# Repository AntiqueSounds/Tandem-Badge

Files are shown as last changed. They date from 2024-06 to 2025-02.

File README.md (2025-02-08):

# Tandem-Badge
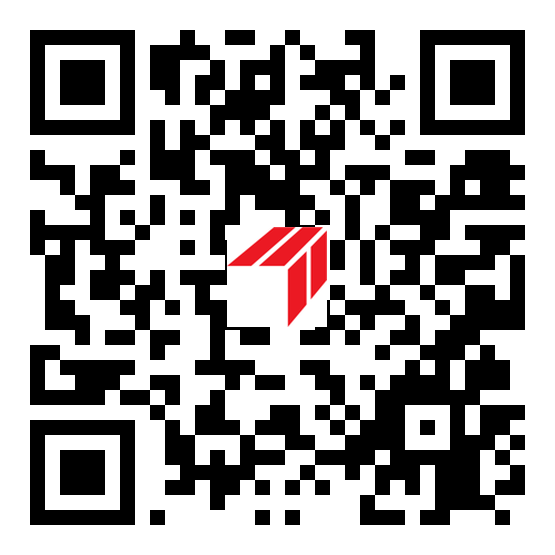
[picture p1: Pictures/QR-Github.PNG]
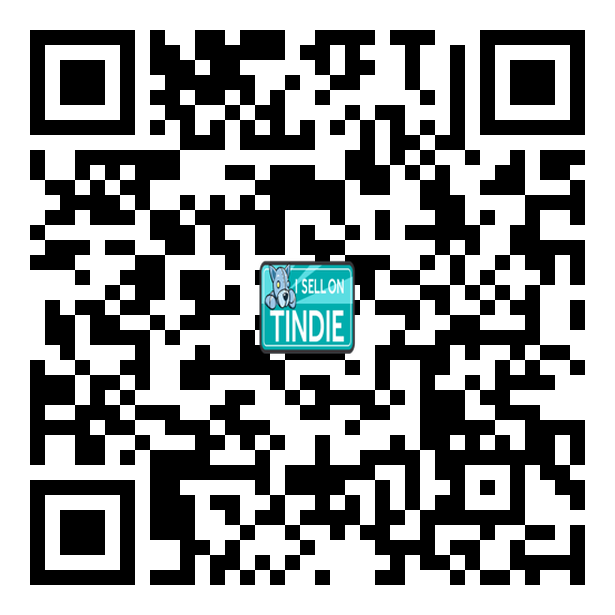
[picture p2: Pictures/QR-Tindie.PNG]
## Tandem 50th Anniversary badge project ✨ &nbsp; &nbsp; &nbsp;    &nbsp; &nbsp; &nbsp; &nbsp;  
This project is a special anniversary badge that can be used for trade shows like the ones used at DefCon.  The standard for SAO badge boards is fully supported in the hardware and software
See:   
[DefCon badges](https://defcon.org/html/links/dc-badge.html)  
[SAO board specs](https://hackaday.io/project/175182-simple-add-ons-sao)

Directions for building the badge and for how to load the software are included here in the top level directory. 

Current software version is V3E (shown on the badge in the lower right corner sideways).   The current badge version is 13 for both top and bottom. The two boards must match versions.  
The SAO boards have separate versioning and do not have to coincide (can be used on any other SAO enabled badge). 

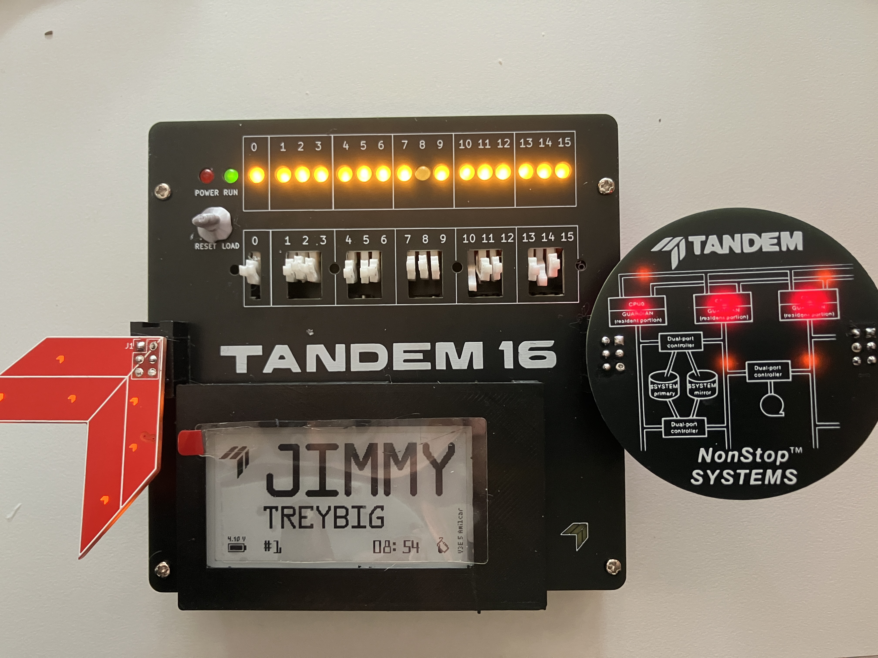
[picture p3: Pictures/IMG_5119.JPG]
Hello my name is


**The switches are FRAGILE, but functional.  Please gently switch them. This was the most difficult part of the whole project. The design and assembly of these switch extensions is still evolving. If a switch extension falls off, it can be "crazy glued" back on.** 

## Functionality
The software has been enhanced to allow serial connection via USB port (115200) to prompt for values to place into persistent memory of the ESP-32. The use of the name loader tool is not unnecessary anymore.

Serial port is set to 115200. The USB is for powerand for serial communication. (Configuration or debugging.) Serial Prompts are for the values shown below in the software persistent memory section. 

Badge software updates can be loaded and upgraded separately from the name load.  There is no need to use the name loader tool. Once set, they persist until cleared manually or over-written by this software. 

Badge software does the following:
Connects to WiFi. It tries the first SSID several times and the second one several times.  
Gets the time.   If fails, then the icon will not show connected in on the display. Time is updated every minute from internal clock.
Time is pulled from NTP pool every 30 minutes
Display is updated to reflect the name and employee number and status of the device. 
Switch management and sleep timer is set up (loops infinately).
See separate documentation for the switch management and sleep/time/display functions. 
Zip code and country code are not yet used. Eventually will be used for weather forecast display. 

### General info:
Power is from the battery that sits under the top board. 
To recharge, you plug the USB into the power source (PC or generic wall charger).  The estimated voltage is shown at the bottom of the screen but is unreliable because the drop from 4.1 to <3.2-ish (lowest that will run the processor) is so quick that it is hard to catch from the data pins. But an estimate is attempted and it looks cool. The number shown is only an estimate and the voltage sample is only taken via some trickery when the system starts up. At full charge it should be 4.1-4.07 volts.  It works fine down in the 3.1 volt range. 

### Software:

There is a persistent memory that holds:
- First Name
- Last Name
- Employee number
- Wifi SSID
- WiFI Password
- SSID2 - Secondary WiFI SSID
- WiFiPassword2 - Secondary WiFI Password
- Time zone offset from GMT (e.g. -5 for Eastern U.S. - default)
- *Country code (default = US - Not used in this release) 
- *Zip Code (not used in this software release)
- *Weather key 
- Sleep timout value (1-9999 minutes)
    
*Not yet used in the software. 

The configuration memory is loaded by setting all of the switches on "1111111111111111" and connecting to the serial port via USB.  The values stay on the device no matter which version of the badge software is loaded in the future. 

Power switch is at the bottom (reset button).   On to the left, off to the right. 
At boot (turn on) the names and information are loaded from memory (above). 
The display is refreshed to a baseline name tag. 
After display is refreshed the LEDs are reset and the switches are processed. 

### Switch usage: 
Normal switch on/off directs up to the led above it. On turns on the LED, off turns it off. 

#### Special switch values:

All switches on forces the device to prompt for memory values as listed above. Name, SSID, etc. 
Switches are considered big-endian from the user perspective (low order is rightmost (#16))

0000000000100010 = High-order switches +10 +14 – Octal 42, a random animated display. There are 7 different possible random displays.  Set/reset the switch to change the rotate display sequence.  
0100000000000000 = Set to little endian "2" = octal “4000"    does a “cylon”  display  
1100000000000000 = Set to little endian “3” = octal "140000"  does a “boot startup display”
1000000000000001 = Forces into sleep mode

The software pulsates the “throbbing” chevron in the lower right.   The power and run LEDs are also pulsed in the software (not related to the switches).

At boot time the device attempts to connect to the first SSID, if it fails it tries the second.  If it connects, then it gets the time and offsets using the TZ parameter.  If the WIFi fails to connect, it shows N/A where time would normally reside. It will retry every 30 minutes.  
Time is displayed at the bottom. The wifi is then disconnected.  Time is maintained inside the device and is updated every minute. The Wifi is connected 30 minutes to refresh and sync for clock float. 
### Display layout:
The display places the First name as the largest text. Text size adjusts as the length requires. Up to 5 characters show at the largest size.  Last name is placed below and is resized according to how long it is. The maximum viable last name length is about 14 characters (if I rememeber correctly?). Anything longer will be truncated without error.
Lowest line shows an estimate of battery power. Do not rely entirely on this image or voltage shown. If it drops below 3.9, you should recharge the device.  
The employee number value is display to the right of the battery.  I believe this is up to 8 characters. I forget.  It will also politely be truncated if it is too long.  
The time is shown if available. If not, it shows "N/A".  The device requires access to WiFi in order to obtain the time. But it is perfectly normal to show N/A if there is no WiFi connected.  
To the right of the time is icon(s) that show state of the device.  While in-flux getting the time, it will change a few times.  Once the device is settled and resting, the icon should be a little hand-held device image.  When sleeping, it shoulds show a little crecent moon. 
To the right of the icons is tiny static informational text:  Version id, a number showing the current sleep time setting, and the name of the prefered SSID to connect to.  
The screen refreshes every minute. 

### "Sleep" logic: 
A timer is set that is a reflection of the timeout request in the sleep time parameter value. This parameter is represented in minutes. 
For example, if the timer is set for 15 minutes, then after 15 minutes with no switch being changed, the device will "sleep".
"Sleeping" does not place the processor into sleep mode. The processor still needs to watch the switches. However, for practical purposes little power is used.  
While sleeping, no LEDS show and no Wifi is used. The SAO port is poewered. So if you want max savings, remove the SAO board to save power going to the solid LEDs on the SAO. Most of the power is being reserved since there are no LEDs on.
I could add the tiny bit of re-work to the board to support wake from processoron a switch toggle, and a real sleep mode, but... Nah. 

### Time logic:
Time is gathered via WiFI from an NTP server. Offset is presented and the HH:MM should reflect current time for the locale represented by the offset value. (-5 USEST, -6 USCST, -7 USMST, -8 USPST, etc.) 
Each minute the screen is refreshed with a new time. The refresh will be less obnoxious in a future release. Currently, the full screen is refreshed which causes it to blink.  
There is also a delay when startup happens (before the switches and LEDs are started). I do lots of nasty slow stuff at startup. 
After 30 minutes, the time is refreshed from the time server (via WiFI) So the net is that WiFi is only used every 30 minutes. 

## SAO ports and SAO boards
### SAO devices are supported on the “dynabus” ports
Software does a candle display on the SAO0 and SAO1 ports GPIO25 and GPIO26 respectively.    The direct power on 5V/G is supported too.   SISO is not used. 

SAO ports are labeled "Dynabus: They are standard SAO V 1.68 ports. https://hackaday.com/2019/03/20/introducing-the-shitty-add-on-v1-69bis-standard/
with 3V, GND, SCL/SDA, GPIO1 and GPIO2 available.    The software uses 3V/GND, GPIO1 and GPIO2.  

The chevron SAO uses 3V for fixed LEDs and GPIO2 for the candle blinking sequence for the other LEDs. 
The Mackie SAO uses 3V for the CPU LEDs and GPIO2 (and GOPI1) for the other LEDS using a candle display. 

The device will drive those pins for any SAO placed onto the SAO header. Several have been tested to work. Even older designs will work as long as 3V and GND are next to each other. The circuit is protected against shorts.  
## Display
### Normal Operative Display
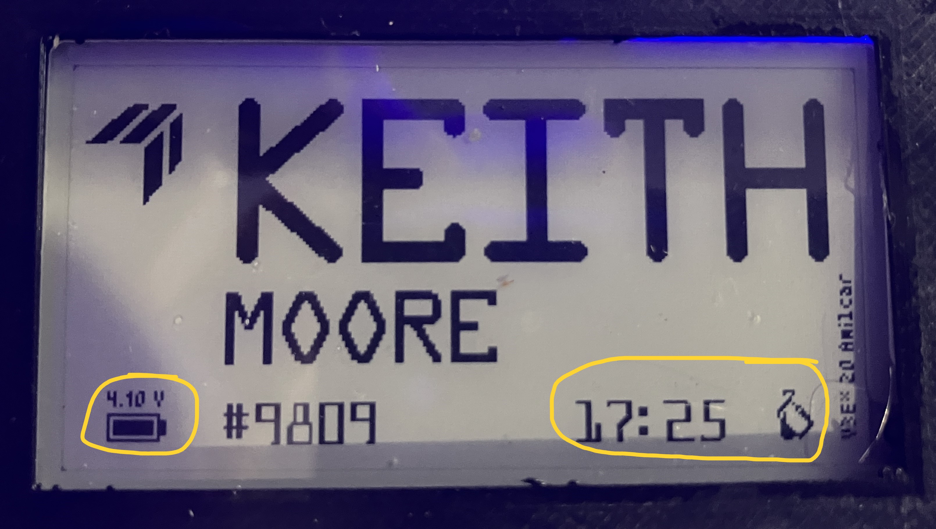
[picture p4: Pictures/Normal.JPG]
Normal Display

If everything is running properly, this display gets refreshed each minute. But the time is not updated from the server that frequently. Wifi is NOT connected when the little "handheld" icon shows. That icon means that everything is updated and running (but Wifi not connected).  This icon should show when everything is working properly.   The battery icon is mostly useless, but it is accurate. By the time the battery bar shows weakening (i.e. < 3.5 volts), the device usually stops. 
### Sleeping Display
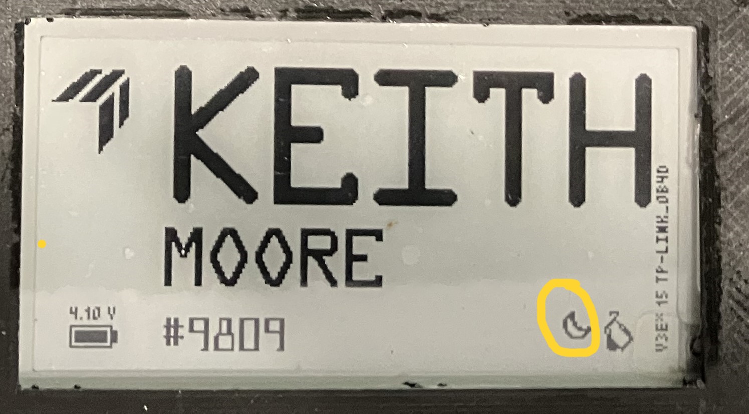
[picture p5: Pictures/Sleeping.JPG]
Sleeping

The sleep icon is shown to the left side of the "handheld" or the "failed Wifi" icon only when the device is sleeping. Device "sleeps" by not updating the time, nor updating the led displays. Power LED on the SAO is still used. Wake by toggling any switch or resetting the device. 
### Right side horizontal tiny characters - Configuration info 
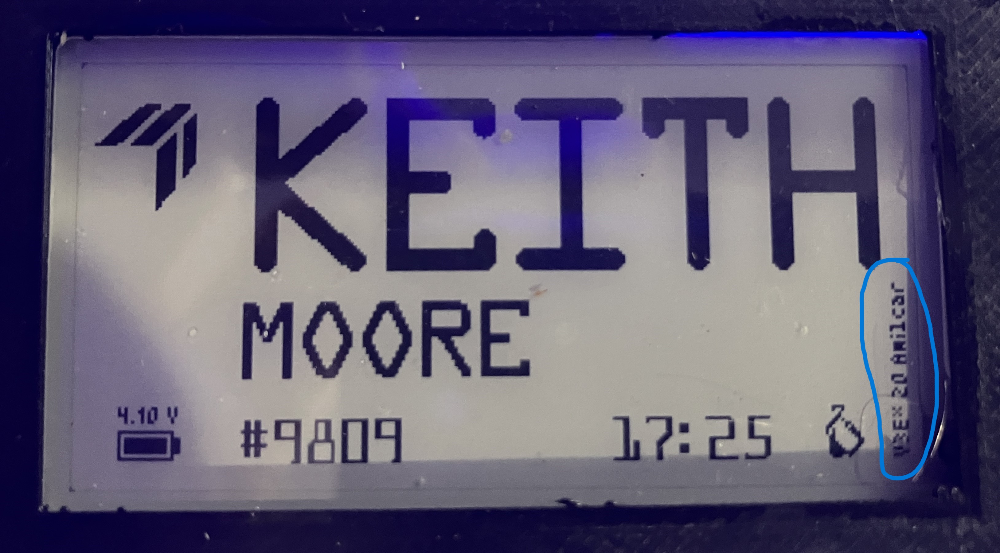
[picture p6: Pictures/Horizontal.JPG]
Horizontals

The sideways tiny letters on the right side of the display show, Version (e.g. V3e*), Sleep timer value in minutes (e.g. 30 minutes), and the SSID that is being used (if it is not connected, the last one that was tried).  
### Boot Display
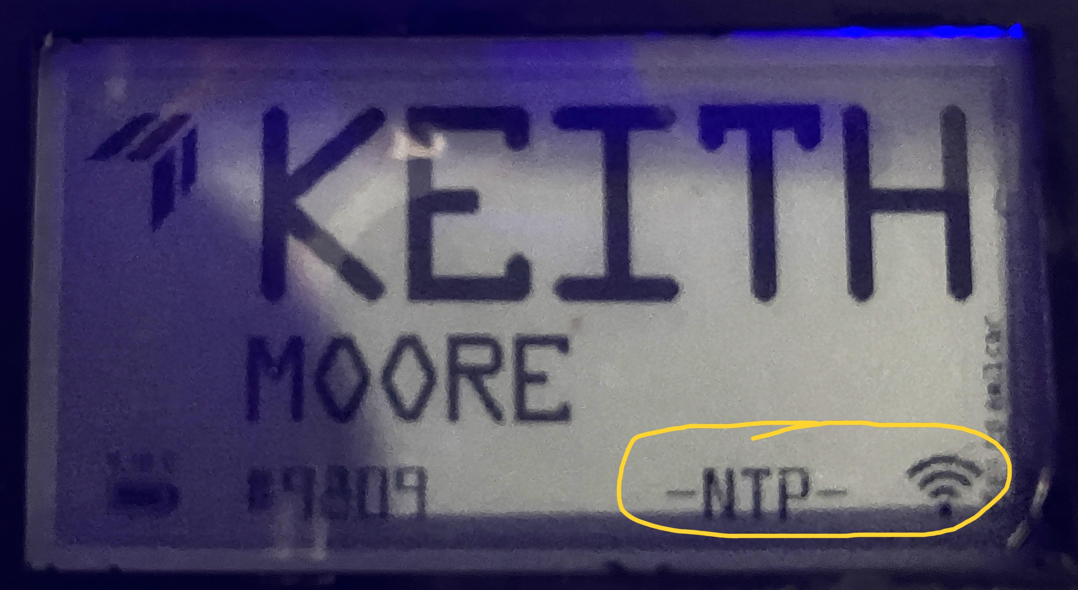
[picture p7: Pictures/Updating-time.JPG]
Booting

This display should just last a second or so. It is briefly shown when the WiFi is connected and the time is being pulled from the NTP server. 
### Failed WiFi Display
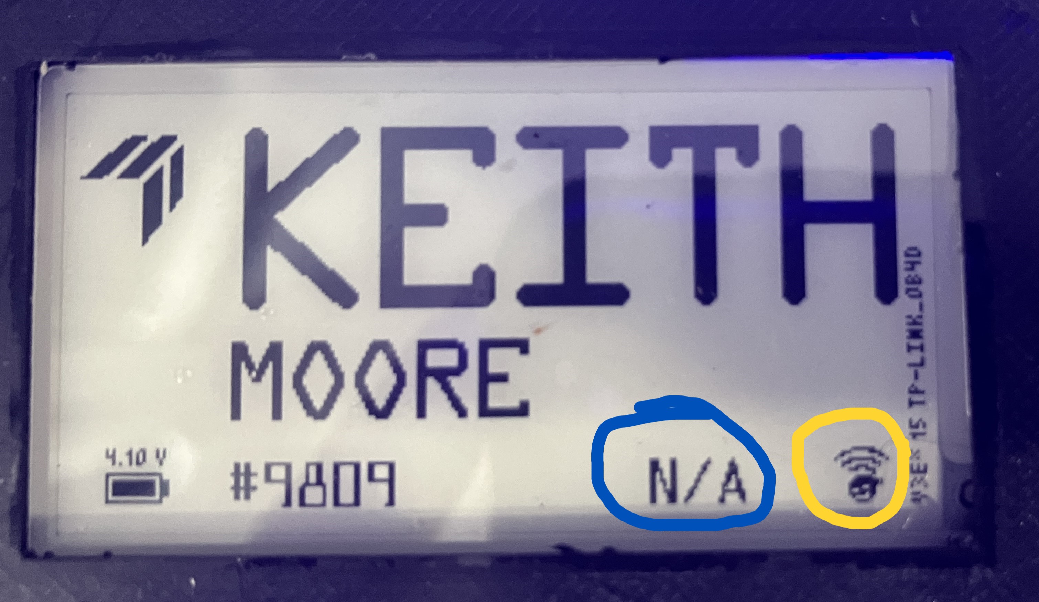
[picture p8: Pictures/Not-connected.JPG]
No Wifi

If the device fails to connect to either the primary or the secondary SSID, this is what is displayed. The device tries again every 30 minutes. 
### Project kit parts and boards
For access to all of the parts and boards, go to the kit site: https://www.tindie.com/products/nixiekeith/tandem-anniversary-badge/ <br/>
Github: https://github.com/AntiqueSounds/Tandem-Badge <br/>
Tindie for the kits: [https://www.tindie.com/stores/nixiekeith/](https://www.tindie.com/products/nixiekeith/tandem-anniversary-badge/) <br/> <br/>
 &nbsp; &nbsp; &nbsp; &nbsp;

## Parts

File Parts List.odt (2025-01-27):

Tandem 16 Badge Parts List

- Non-Electronics parts
  - PCB boards
    - Top V13
    - Bottom V13
    - Random bottom or top for the underside (optional)
  - 3DP Parts
    - Display cover shroud (black)
    - Faux key top and bottom (silver)
    - Switch extensions (16) white
  - Standoffs
    - 8-9 mm M2 (4)
    - 2-3 mm M2 (4)
    - M2 screws (4)
    - M2 nuts (4)
- Electronics parts
  - Sockets for IC (4)
  - 3-way switch DIP (5)
  - 1-way switch DIP (1)
  - Resistor array 471O (2)
  - Resistor array 10kO (2)
  - TH resistors 67O (3)
  - generic diode or jumper wire (1)
  - 6 pin female header with extended pins (2)
  - 3MM yellow led (16)
  - 3MM red led (2)
  - 3MM green or blue LED (1)
  - 13 pin (cut manually) female
  - 13 pin male extended long pins (for display)
  - 74HC595 IC (2)
  - 74HC165 (2)

Parts for SAO (not included)

- Reverse gull-wing LED green (3)
- Reverse gull-wing LED any color (9)
- SMD resistor 70-90O (3)
- 6-pin male shrouded header (2)

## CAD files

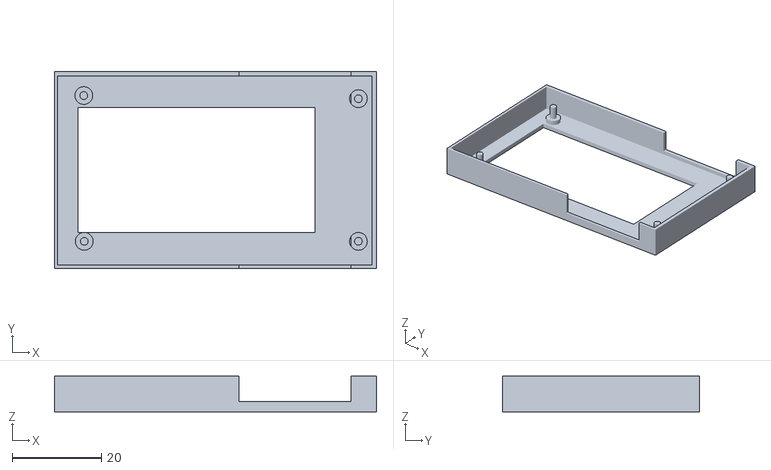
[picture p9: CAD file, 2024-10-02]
3DP Files/paper top.stl
72.0 x 44.0 x 8.00

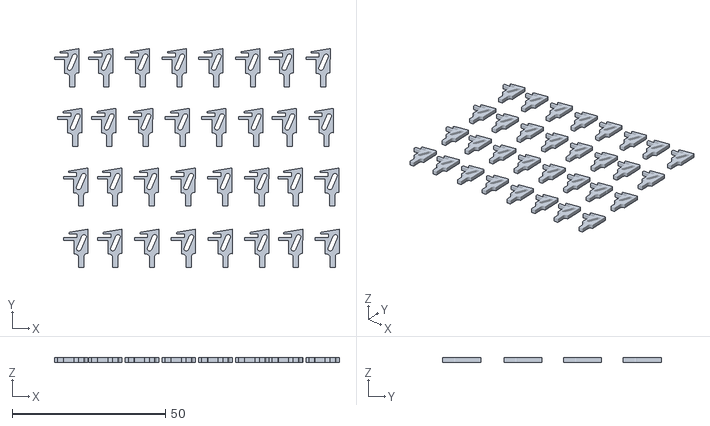
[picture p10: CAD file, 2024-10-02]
3DP Files/switch levers.stl
93.1 x 71.5 x 1.60

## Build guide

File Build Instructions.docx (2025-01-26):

# Tandem 16 Badge Building Instructions

# Overview

The Tandem Badge project is a project that allows building and customization of a convention badge that can be worn at trade shows. The idea is a spin of the DefCon badges (https://defcon.org/html/links/dc-badge.html), and it leverages the SAO (https://hackaday.com/2019/03/20/introducing-the-shitty-add-on-v1-69bis-standard/) interface as described in the DefCon (https://defcon.org/html/links/dc-badge.html) sites.

The badge is a 2-layer design that has the main electronics on the lower board with a top cosmetic PCB that covers the electronics. A paper white display provides a persistent name badge and is also the microcontroller for the electronics. The device is designed as a tribute to the original Tandem computer panel created in 1975-76 and used until the three production Tandem systems prior to the release of the VLX (T16 (aka TNS-I) TNS-II, and TXP). The panel on these is shown below. It has two LEDs that were used for displaying “power” and “run” (TNS-II and TXP only), and 16 more LEDs placed in a row to the right, next to the two other LEDs. The 16 LEDs were framed with a silkscreen to break the 16 bits into Octal values (groups of 3) with a single remaining LED to the left of the groups of 16. The silk numbers the bits in order from 0 (leftmost) to 15 (rightmost). Octal values are entered as big endian (e.g. %42 = 0 000 000 000 100 010).

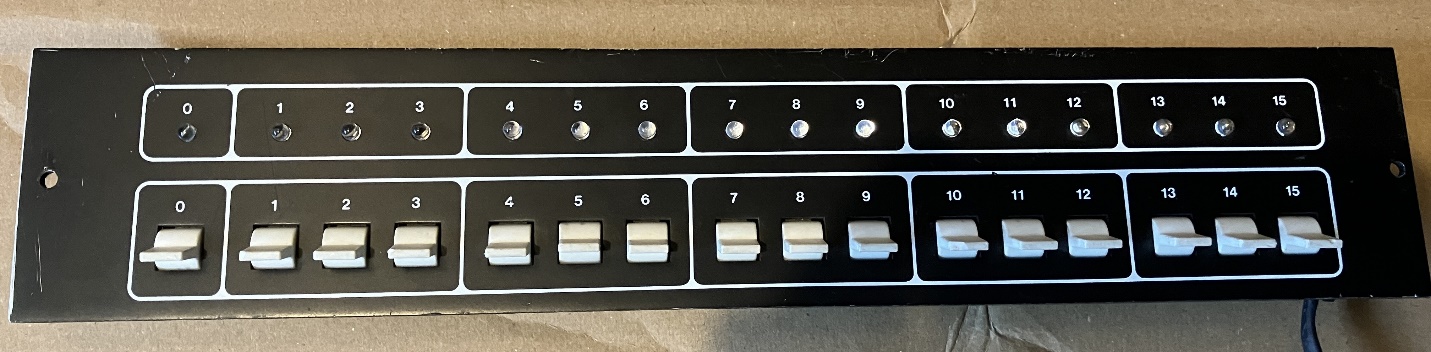
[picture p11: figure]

Figure 1- T-16 / TNS-1 switch panel

Under the row of LEDs there are switches that set and reset the LEDs (in the real computer panel they also set/reset the registers in the computer).

For each switch, there is a corresponding LED above it. Individual switches can be set to any value.

The badge simulates the behavior of this design. It uses a “register” value to hold the current switch configuration. In some cases, the value of the switches causes special actions. These special switch values are documented elsewhere in the operation instructions on Github (https://github.com/AntiqueSounds/Tandem-Badge) (see above QR code).

# The Tools required to build the badge

The electronics are placed using through-the-hole components. There are no surface-mount parts in this design. Soldering should be simple, even for beginning skills level soldering.

- Soldering iron and solder
- Ethyl cyanoacrylate “Crazy” glue (GELL stye greatly recommended)
- Small screwdriver (usually using a phillips screw)
- Pliers to hold the small nuts.

# Parts List

## Badge parts

- 3D Printed parts (as part of the kit need to be printed prior to the build)
  - DIP switch extensions (16)
  - Display cover (optional shroud over the display to make it nicer)
  - Simulated reset key
- 3MM offset spacers 8-10MM long (4)
- 3MM offset spacers 3MM long (4)
- M2 Screws (4)
- M2 Nuts (4)
- Extended 2x3 female headers (2)
- 13 pin female headers (2)
- 13 pin extended (long) male headers (2)
- 9 pin resistor array (8 - 10k resistors) (2)
- 9 pin resistor array (8 - 470 resistors) (2)
- Small standard (3MM) LEDs (amber or yellow) (16) [Or blue for the Roel Pieper edition 😊]
- Small standard (3MM) LEDs (red) (2)
- Small standard (3MM) LED (green) (1)
- 3 switch DIP (MUST BE OFFSET, NOT STANDARD DIP SWITCH!) (5)
- 1 switch DIP (MUST BE OFFSET, NOT STANDARD DIP SWITCH!) (1)
- 67 ohm or near value (60-80 ohm) resistors (3)
- 74HC165 in DIP configuration (2)
- 74HC595 in DP configuration (2)
- DIP Sockets (16 pins) (4) (recommended but optional)
- Lithium battery 3.3V/4V
- Generic Diode (recommended) or a jumper.
- LilyGo ePaper (paperwhite) T3 display and ESP processor.
  - Software - Xinyuan-LilyGO/LilyGo-T5-Epaper-Series (github.com) (https://github.com/Xinyuan-LilyGO/LilyGo-T5-Epaper-Series/tree/master)
  - LILYGO® TTGO T5 V2.3.1_2.13 Inch E-Paper from Lilygo on Tindie (https://www.tindie.com/products/lilygo/lilygo-ttgo-t5-v231_213-inch-e-paper/) (make sure includes the 9102 chip)

## Optional SAO Parts

SAO boards use reverse gull-wing LEDs. Most also use SMD resistors of approximately 65-90 ohms. The header on each side is a shrouded male 6-pin. These should be the standard SAO compatible design. Each Tandem Badge SAO is different, but they all use the same header, resistors and LEDs.

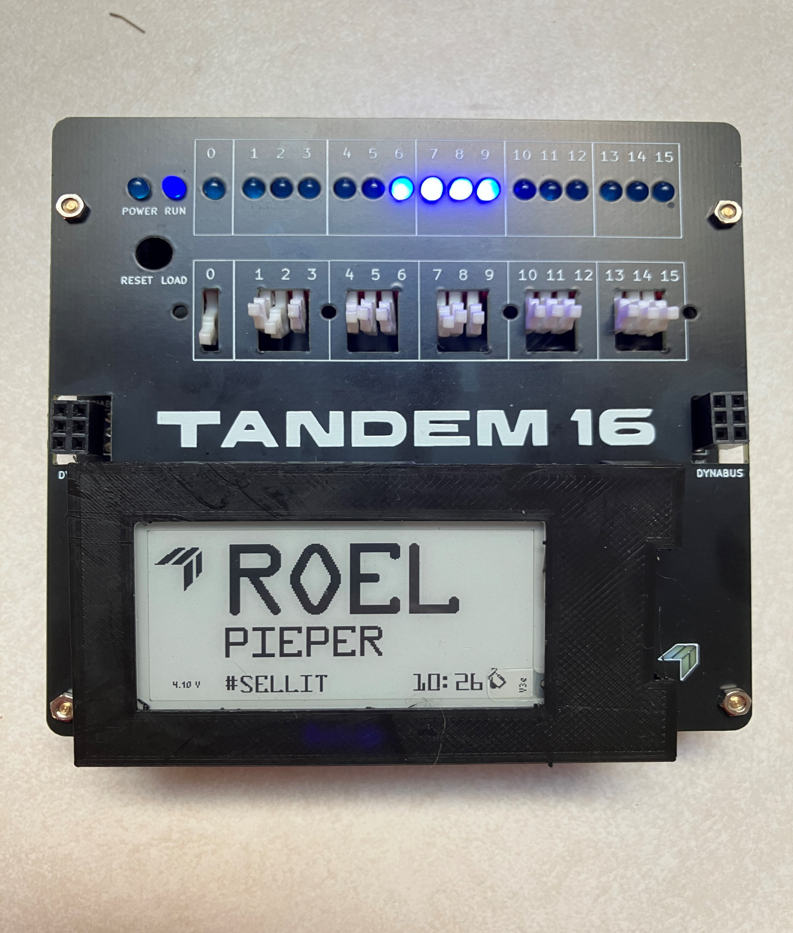
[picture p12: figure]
A black electronic device with a screen and buttons

Finished Build. This one was built with blue LEDs as a joke.

# Step 0

Print or obtain the 3D printed items: 1 Key with base, 16 or more white lever extensions, and one display cover/shroud

# Step 1

Place the longer 8-10MM stand-off spacers onto the main board from the top with the female facing down, Secure the shorter 3MM (or less) spacer using the male side through the hole to hold the top/longer spacer onto the main board. Repeat for each corner of the main board. In the end, you should have all 4 spacers placed with the short spacer on the bottom and the longer spacer on the top. This is a temporary placement of these stand-offs.

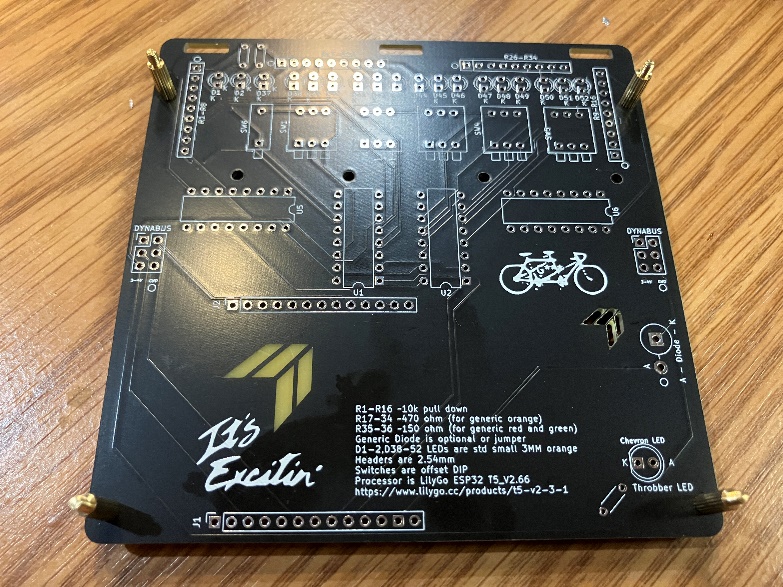
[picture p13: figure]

Figure 2- Board with spacers placed

# Step 2

Place one of the three (~67 ohm) resistors into the resistor component holes. Orientation does not matter. Solder these leads to the board.

Place one of the red LEDs into the Throbber LED component holes. Note orientation. Anode (long leg) on the right, flat side left. DO NOT SOLDER the LED YET!

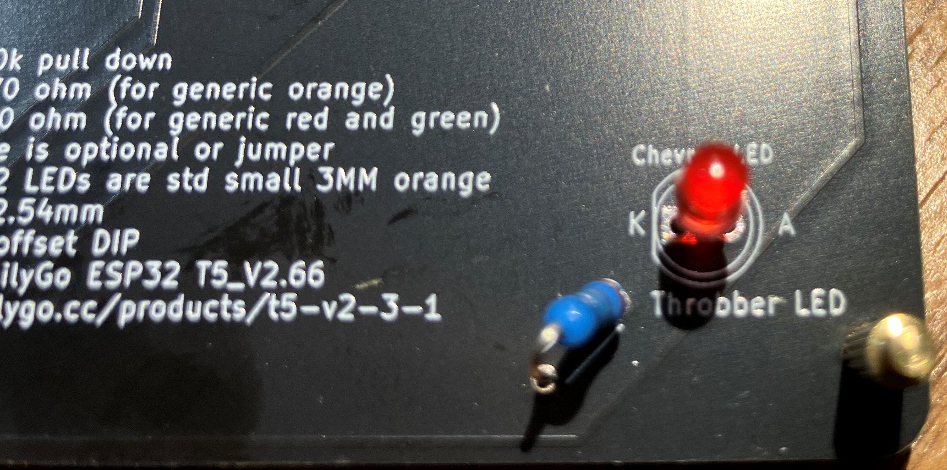
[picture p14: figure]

Figure 3 - lower red LED place loosely

# Step 3

Place the two leftmost top LEDs (red and green) into the D1 and D2 holes. MAKE SURE the ANODE is toward the lower side of the board and the cathode is toward the top edge of the board. Early versions of the board silkscreen have the A/K reversed. K should be on the top, and A on the bottom (with the flat side being the K at the TOP). This orientation is the same for ALL of the LEDS at the top of the badge.

Once the red and green LEDs are placed, place all of the remaining 16 yellow or orange LEDs into the remaining LED holes. Orientation should be the same for all LEDs. Flat side of the LED up toward the top of the board. Long lead toward the lower side of the board.

# Step 4

Pick up the lower board and let the LEDs slide and rest onto the lower board (freely) Same for the remaining red LED that sits on the lower right side of the main lower board.

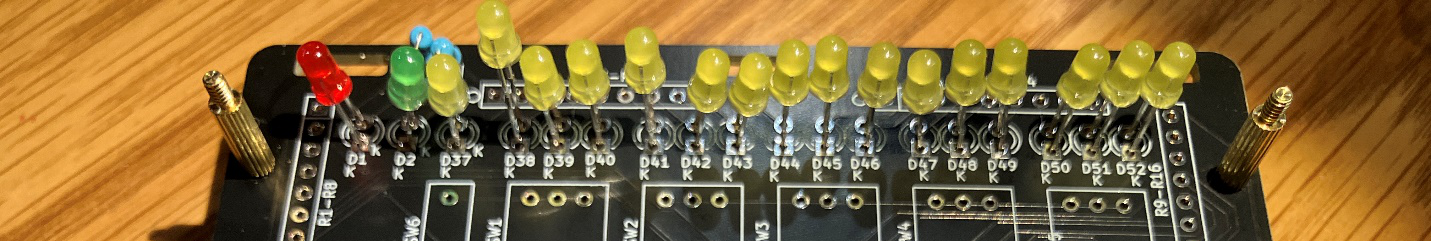
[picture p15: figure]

Figure 4 - LEDs placed loosely into the holes

Rest the top board over the spacers of the bottom board. Install 2 to 4 screws to hold the top board onto the lower board. Then flip the entire badge over (both boards upside down). Guide each of the loose LEDs into the corresponding hole in the top board. Make each one fit directly into a hole and seat down all the way to the LED stopper. LEDs should all fit perfectly into each hole before proceeding. Check that ALL of the LED pins are aligned the same and that they are correctly placed before soldering.

Check the remaining red LED in the lower corner of the badge. Make sure it is resting with the tip on the little chevron on the top board. The LED should not be bent and should rest on the chevron before soldering.

Solder all LED connections now. Double and triple check orientation before clipping the remaining wire short.

Remove the top board. Leave the spacers on the corners. You will need those again on step 9.

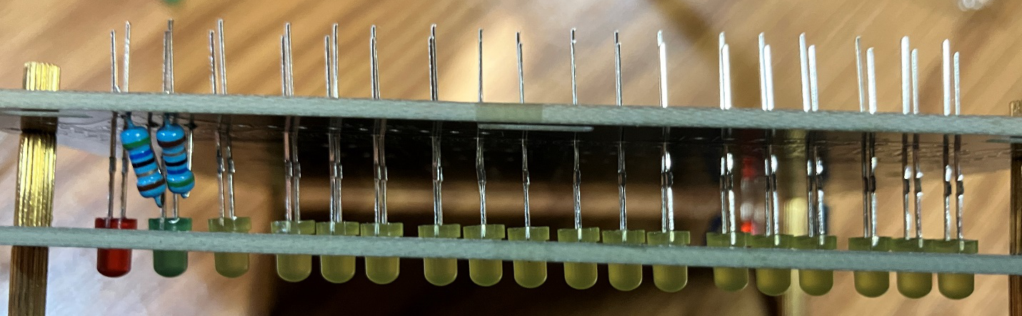
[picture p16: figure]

# Step 5

Place the diode or a jumper wire to the diode at the lower right side of the board. Make sure of the orientation. Cathode (bar on the diode) should be at the top hole. Solder and trip as appropriate.

# Step 6

Place resistor arrays. Be sure to place the proper value resistors into the correct locations and ensure that the orientation is correct. Match the dot on the board with the dot on the array.

The arrays at the top are marked 471. Align the dot on the array to align with the dot printed on the circuit board. (left of the board facing up). R17 through R34 are 471.

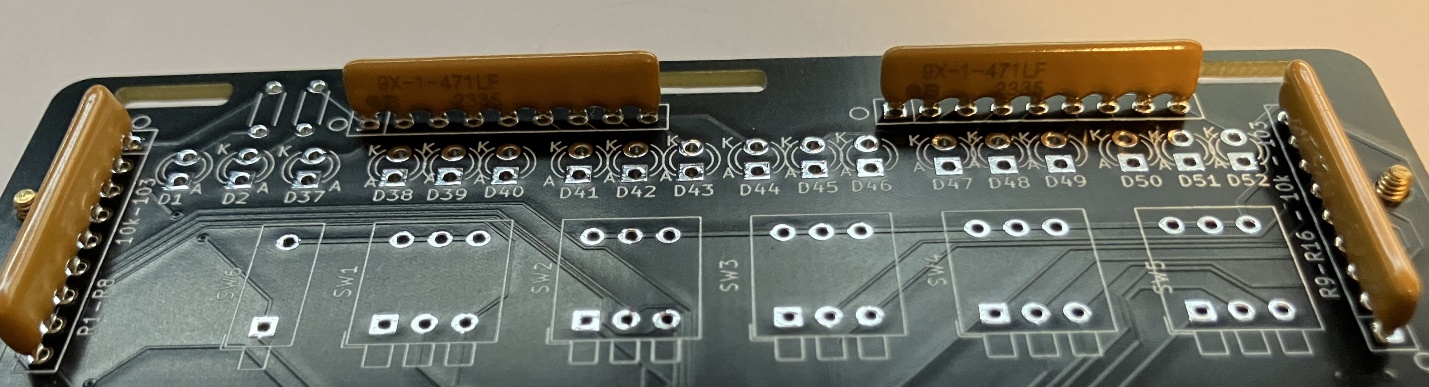
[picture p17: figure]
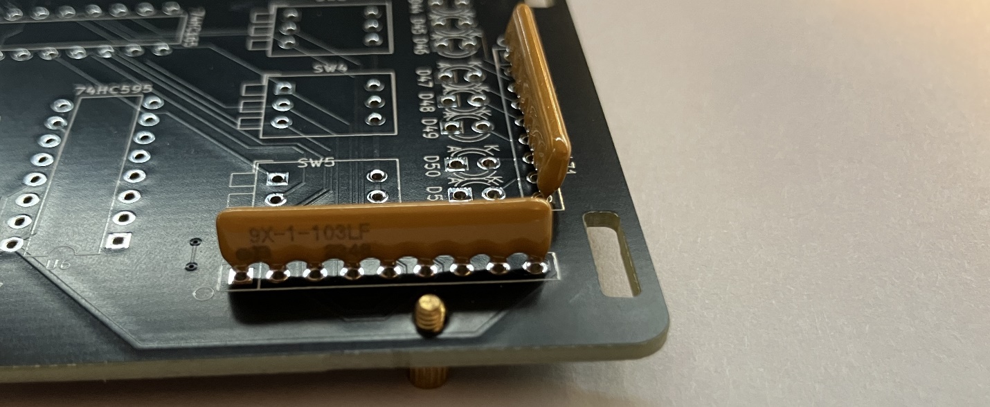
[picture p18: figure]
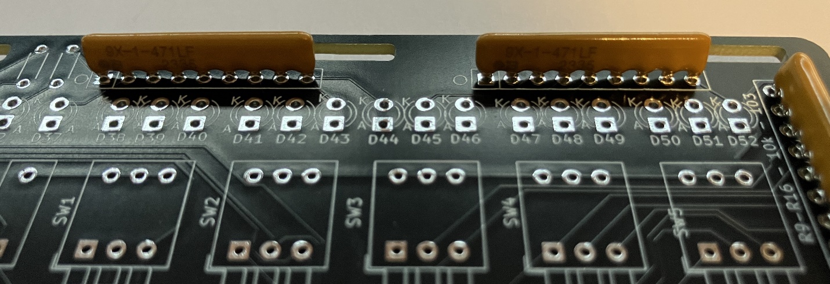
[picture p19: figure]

The remaining two 103 arrays are placed vertically into their locations. NOTE that these arrays are placed in opposing directions from each other. Make sure you place the dot with the dot on the array. When the 103’s are placed, the leftmost should have the dot on top, while the rightmost one has the dot placed on the bottom.

Solder these to the board to complete this step.

# Step 7

Place the four IC sockets. Orientation of these sockets is shown on the board. Do not mount the ICs into the socket yet. Solder all of the connections to the board. If you make a mistake on orientation, it is not a disaster. But make sure you note it when you place the ICs. The sockets can be wrong, but the IC insertion (later) cannot be.

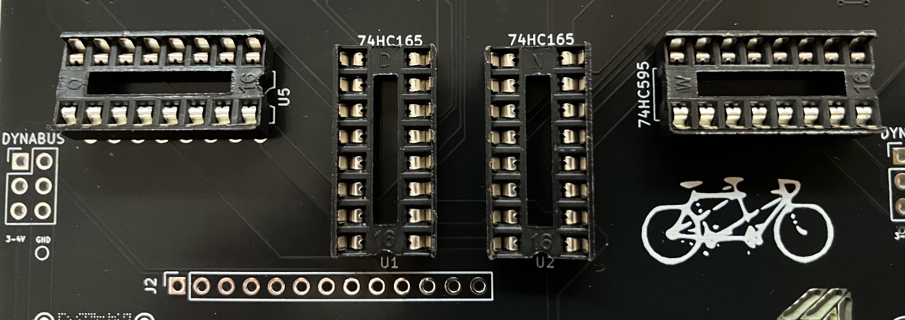
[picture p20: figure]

# Step 8

Place the DIP switches. 5 sets of three, and one set of one. The easiest placement is to do one at a time from one side to the other. Or, you can place them all and solder them all. Caution to be sure that the DIP switch is FACING TOWARD THE BOTTOM. If you invert these, this will be really annoying to fix. (Not that this has ever happened before?)

# Step 9

Place all of the headers.

This step is best done with the top board placed temporarily. Place the top board back onto the spacers and secure it to the stand-off using another stand-off spacer that is as deep as the 6-pin female header with the long pins. In other words, place the stand-off so that it can be used to space the header to the table when the device is upside down.

If this does not make sense, the objective is to solder the two female headers to the “dynabus” circuit board holes such that the most possible length is used. There should be just enough length on the headers to be soldered onto the lower board. Do this for both 6-pin headers. The header should protrude fully through the top board. DO NOT PLACE IT LEVEL WITH THE TOP BOARD. IT NEEDS TO PROTRUDE above the top board. See the diagram if this is not clear.

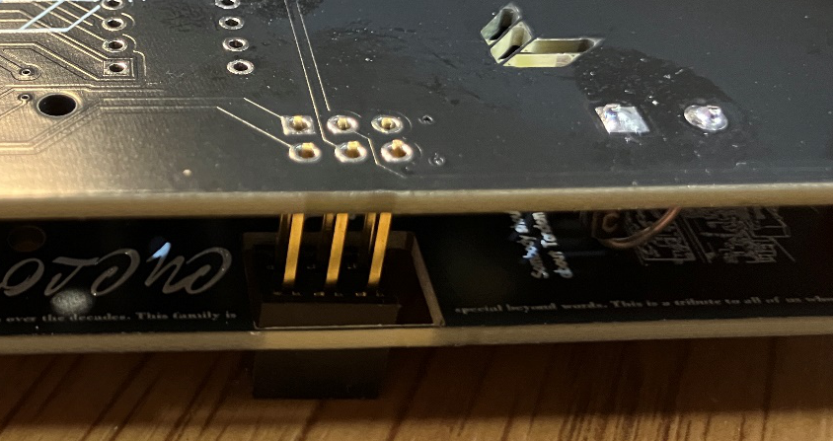
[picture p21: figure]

Figure 5 - Bottom of board showing the fully extended long pins

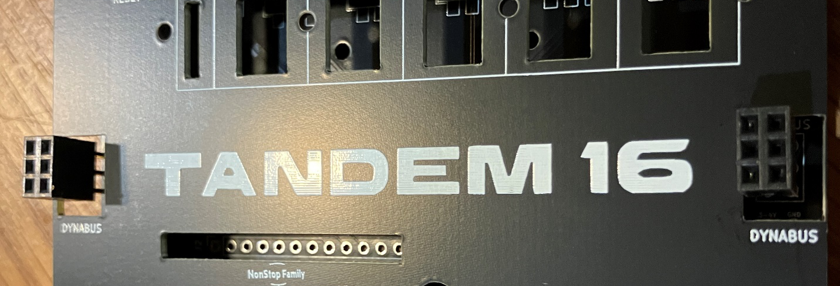
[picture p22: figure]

Figure 6 - Female headers extended through the top board.

Break the female header lengths into two 13-pin lengths. Plug the 13-pins into the LONG male header pins. DO not use standard length male headers. Use extended length ones. Two 13 pin headers should be placed through the top board and into the bottom holes. Before soldering anything, place the display board onto the male pins that protrude through the entire kit. Make sure all pins are aligned on the display card. Solder the display to the male header pins first. The heat dissipates and the soldering is more difficult than on the PCB. This is normal. Use flux if you need to. Be patient and let the component warm enough to deliver the solder for each of the 26 solder points on the display. Be careful, but persistent with each solder taking a long time because of the heat dissipation. It is normal for this to be a tie-consuming step. A good connection in all pins is critical here.

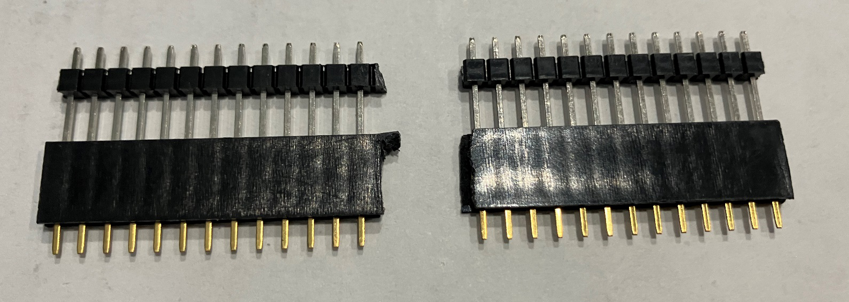
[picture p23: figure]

Figure 7 - Header pins Trimmed and prepared for placement

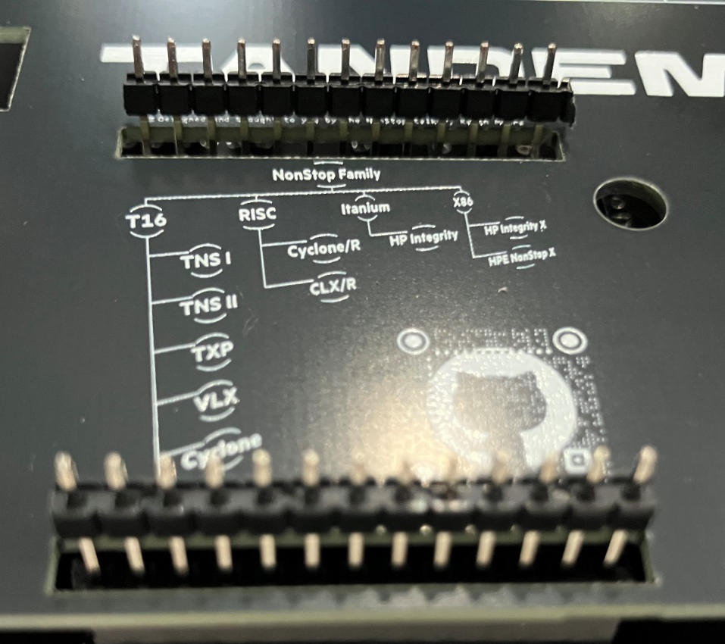
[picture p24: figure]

Figure 8 - Headers placed prior to soldering -No solder on bottom side yet

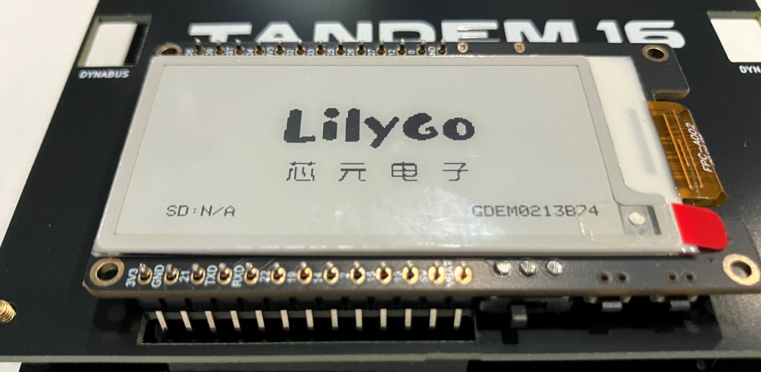
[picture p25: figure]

Figure 9 - dry placement of the display on top. Solder these pins first

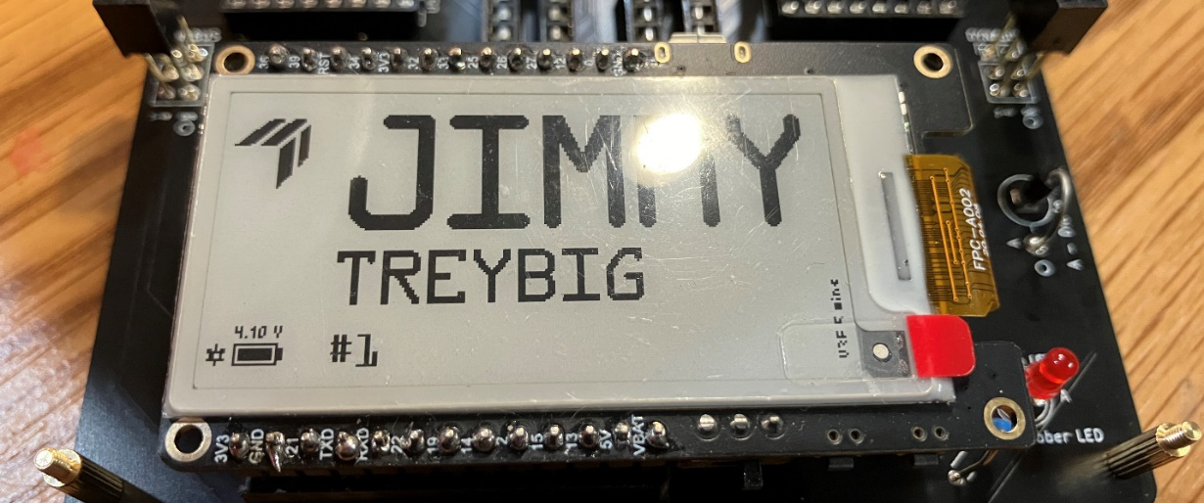
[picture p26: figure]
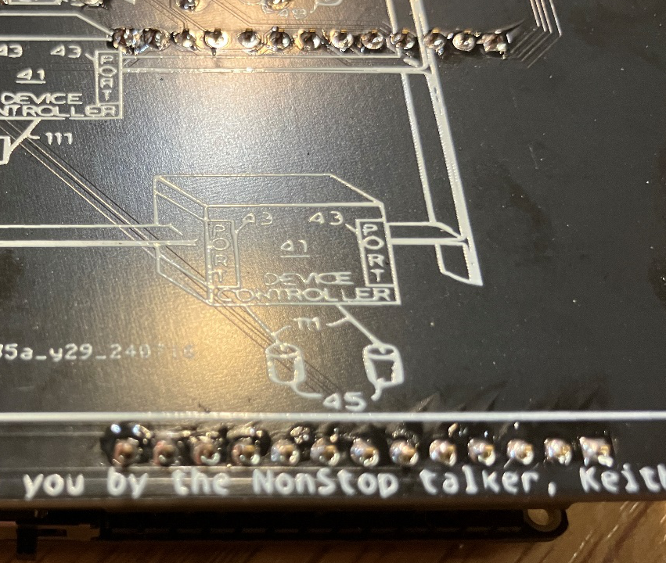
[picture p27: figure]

Figure 10 - Solder bottom pins after the display-side pins are soldered

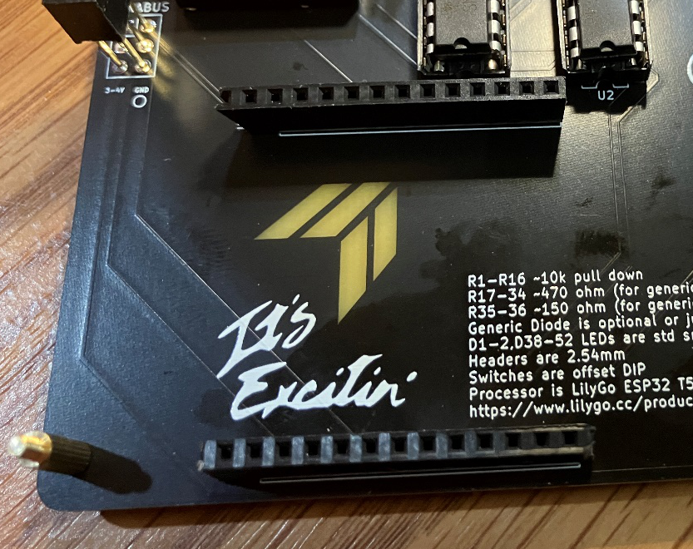
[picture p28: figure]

Once the display header is completely soldered. Carefully flip the kit over and solder the two 13 (26) pins into the board on the bottom.

Figure 11 - Display and top board removed. The female headers should be solid now.

# Step 10

Place the components onto the main board and prepare the battery cable.

Unplug the display from the female header. Set aside. Remove the top board again. Place the integrated circuits into the sockets and make sure the orientation is correct to the marking on the board. Make sure that the proper chips are placed into the proper socket locations on the board. The 595 are horizontal and the 165 are vertical.

# Step 11

Final assembly.

If you have not placed the little miniature key, it can be placed now. The key goes through the top hole and the little cap captures through the hole and locks with a gentle 1/8 turn. Be very gentle. It is easy to break the stem. It only has to turn just enough to set. Less than 1/8 of a turn should suffice. If required you can fabricate some tape below (or glue) this cosmetic part. When it works, it will spin nicely. But it is not a necessary part at all.

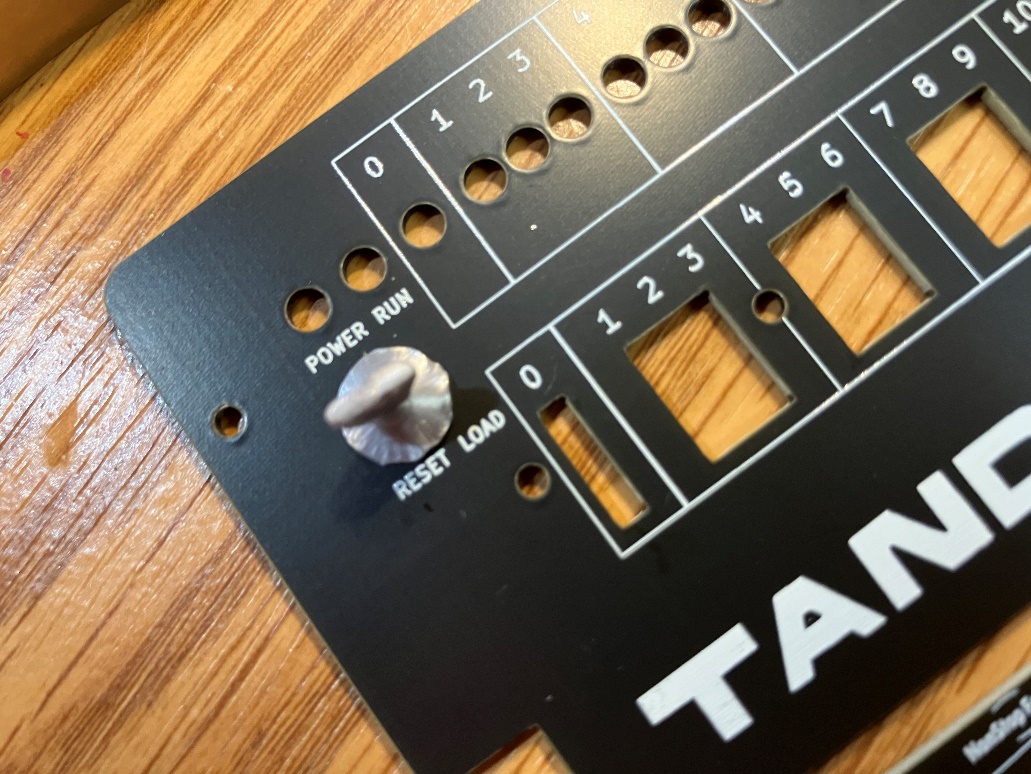
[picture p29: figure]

Look over everything If everything is correct and soldered, process to place the battery between the female headers with the wire protruding to the right side. Place the wire through the small circular hole on the top board. Secure the top board to the stand-off spacers with screws or nuts depending on which way the header is facing.

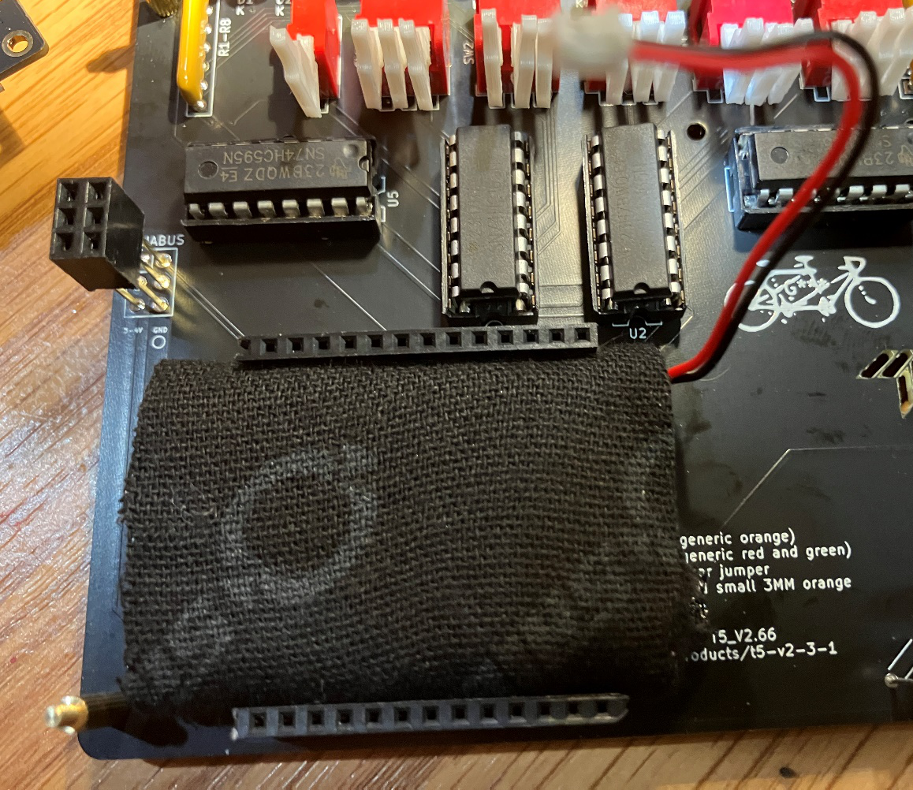
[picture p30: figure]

Figure 12 - Battery may appear different

If you have a shroud for the display, place it over the display and touch the plastic pins that go through the display corner holes with the soldering iron to melt the 4 corners in place.

Once the top is secure, first, plug the battery into the female plug end center bottom of the display board, then carefully insert the display header back into the female header through the slot in the top board (like you did when you soldered it in place). The battery plug is keyed and can only go in one way. Do not force it the wrong way.

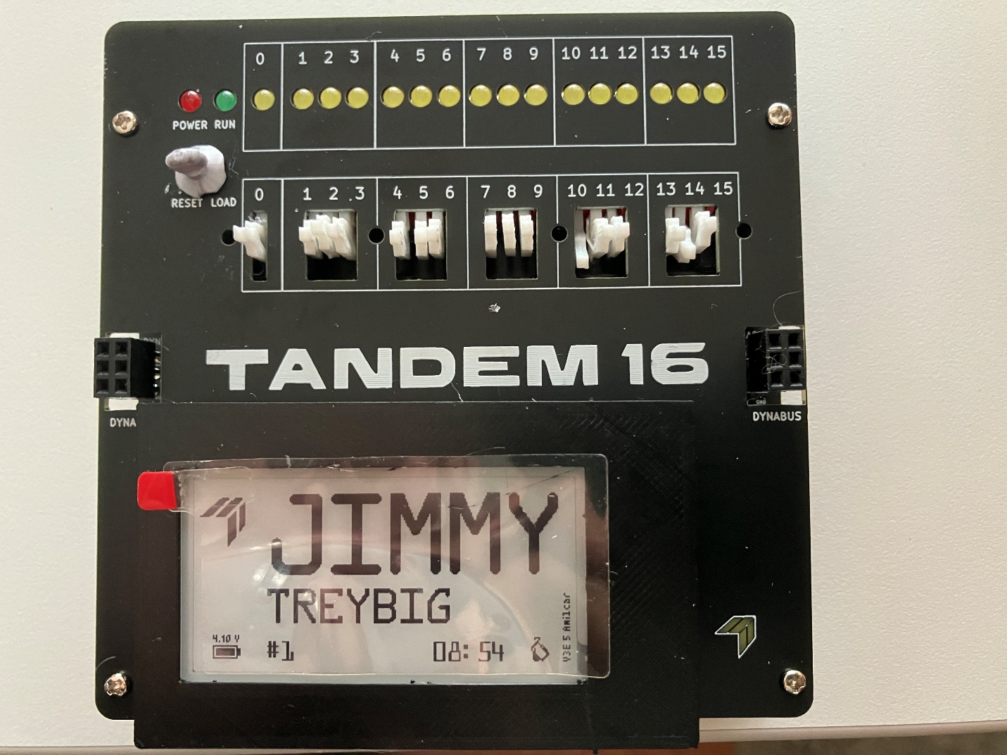
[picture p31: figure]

Optionally (recommended) place a dummy bottom board with the short stand-off spacer. The dummy board is just used to prevent catching the bottom pins against anything – and prevents short circuits. The dump board can be oriented in any way or can be either a top or bottom dummy board. I use old bad boards. One should be provided.

# Step 12

Carefully turn on the device by sliding the little switch on the display. Left is on, right is off. The two push switches are for reset and for programming via interrupt. The reset can be used to reboot. The other button is not used.

If the unit is programmed, you can proceed to configure the memory for personalization. If not, the processor will need to be programmed using Arduino or AVRdude. Instructions for that are elsewhere.

# The SAO board(s) (Optional)

The SAO boards use reverse gullwing LEDs (11) and small SMD resistors(3). Any can be used and the board shows the location and range of possible components. LED orientation is marked on the board with a dot for the cathode (K).

Use Male header with shroud for the pin connector to the main board. The SAOs designed for this project will have pins that can be placed onto either side of the main board “dynabus” header.

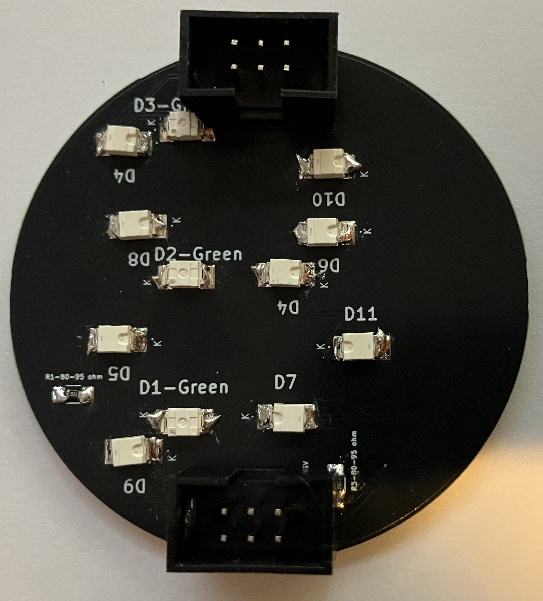
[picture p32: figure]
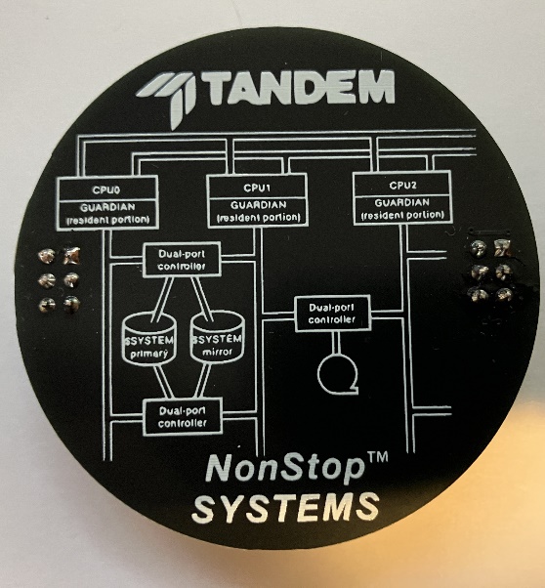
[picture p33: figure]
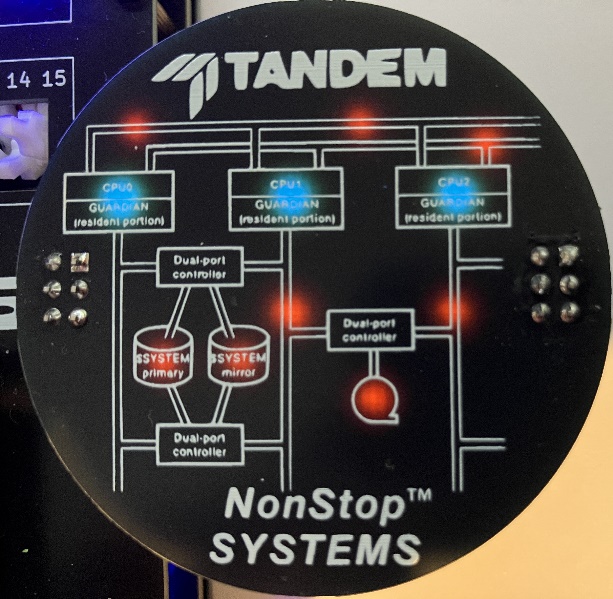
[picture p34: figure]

# Final Step

Enjoy!

I am at nonstoptalker@hpe.com or keithmoore@acm.org.

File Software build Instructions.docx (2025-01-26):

# Tandem 16 Software Build Instructions

# Overview

The Tandem Badge software source is provided and can be built and loaded most easily using Arduino IDE. This is the tool that was used to develop and deploy the software to the badge.

It is theoretically possible to used a loader directly to the device using the USB, but I have not done this.

These instructions walk through a complete install of Arduino IDE through loading onto the badge device. For instructions on how to assemble the device, see the assembly document.

# The files required to build the badge software

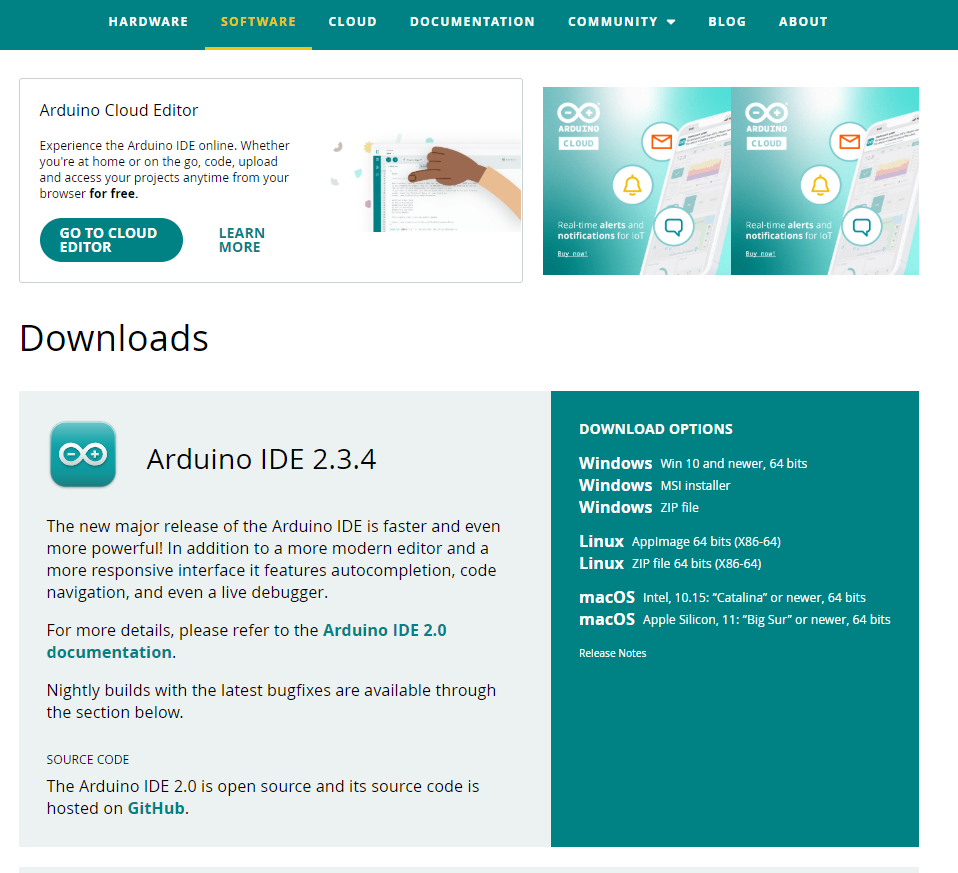
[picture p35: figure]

1) Arduino IDE software – I used Windows, but this should work on Linux or Mac.

Figure 1- Arduino Download

2) The source code. Current version is provided in git. The source code is <file-name>.ino (e.g. Badge_V1_3e.ino or similar name with .ino extension.)
3) Several arduino libraries are required:
- Timers
- WiFi
- WiFiUdp
- TimeLib
- NTPClient
- Jled
- Time
- AdaFruit_GFX

These libraries will be applied and created as part of these instructions.

4) Fonts. Fonts are provided in the github repository and will be placed as part of these instructions.
5) USB cable (optional 90-degree cable converter) and a PC with a USB. I used Windows, but it should work with Linux or Mac.

# Step 0

## Install the Arduino IDE tool

Download the Arduino IDE software. Install the software in entirety following normal software installation processes. Software is found here: Software | Arduino (https://www.arduino.cc/en/software)

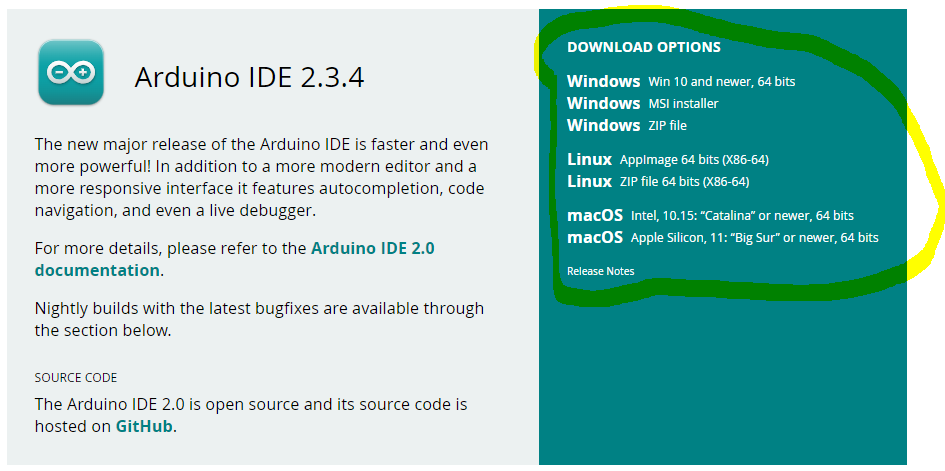
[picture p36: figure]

Figure 2 - Arduino Download Select

# Step 1

## Install the board confuguration

Once the IDE is installed, the boards need to be added for these specific ESP computers that are used for the badge.

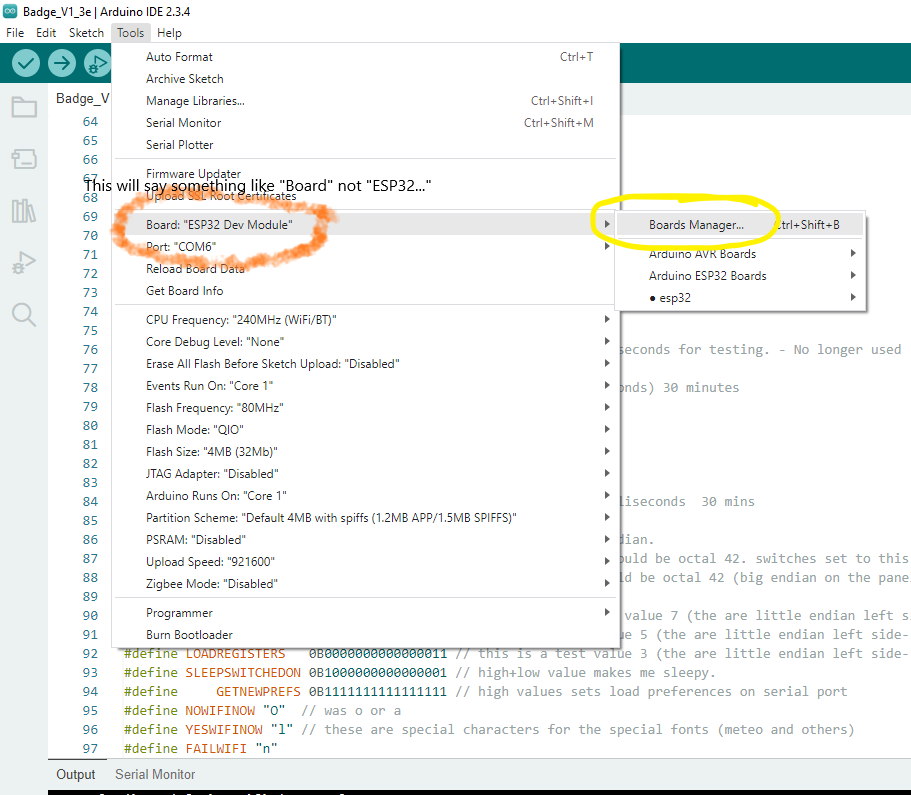
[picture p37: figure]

Figure 3 - Open the board manager tab

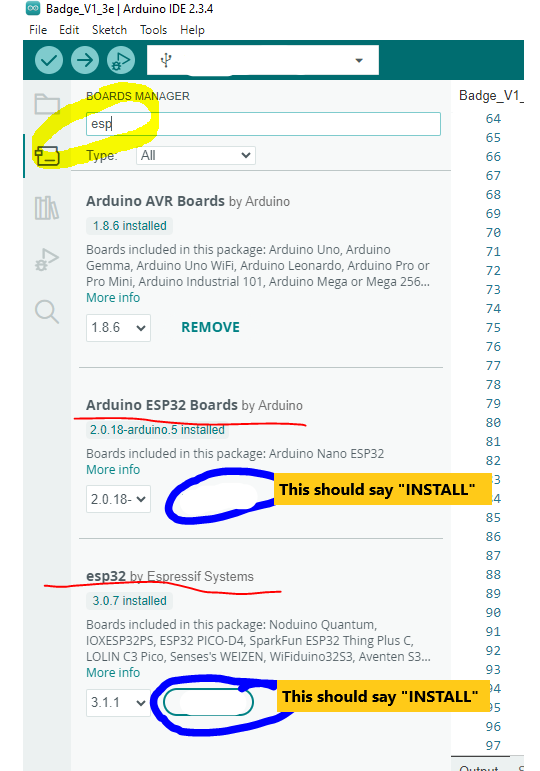
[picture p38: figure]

Figure 4 - Search for ESP board

Click on the INSTALL button for both of the ESP32 board sets. I do both, but we only need the esp32 one. You can just select esp32 by Espressif Systems. This takes several minutes. If it asks for any additional sets, approve them. (Not likely.)

Eventually you get this:

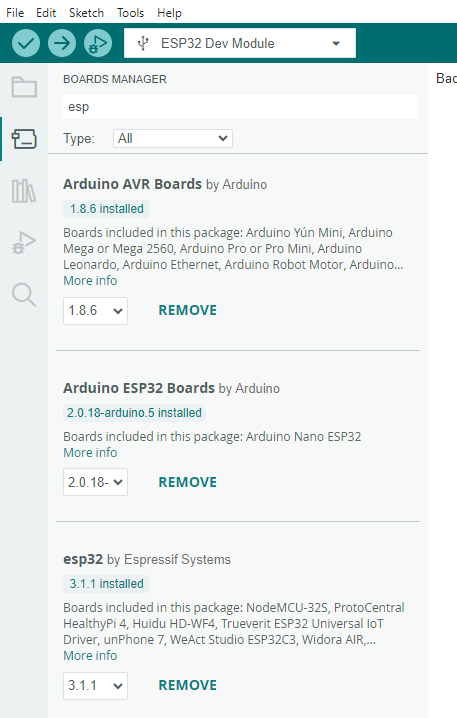
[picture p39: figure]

Figure 5 - Board libraries installed

Select the stair step menu Tools/Board/esp32/ESP32 Dev Board. The Tools/board value should now be ESP32 Dev Module and the board configuration parameters should all be populated (speed, debug, etc.)

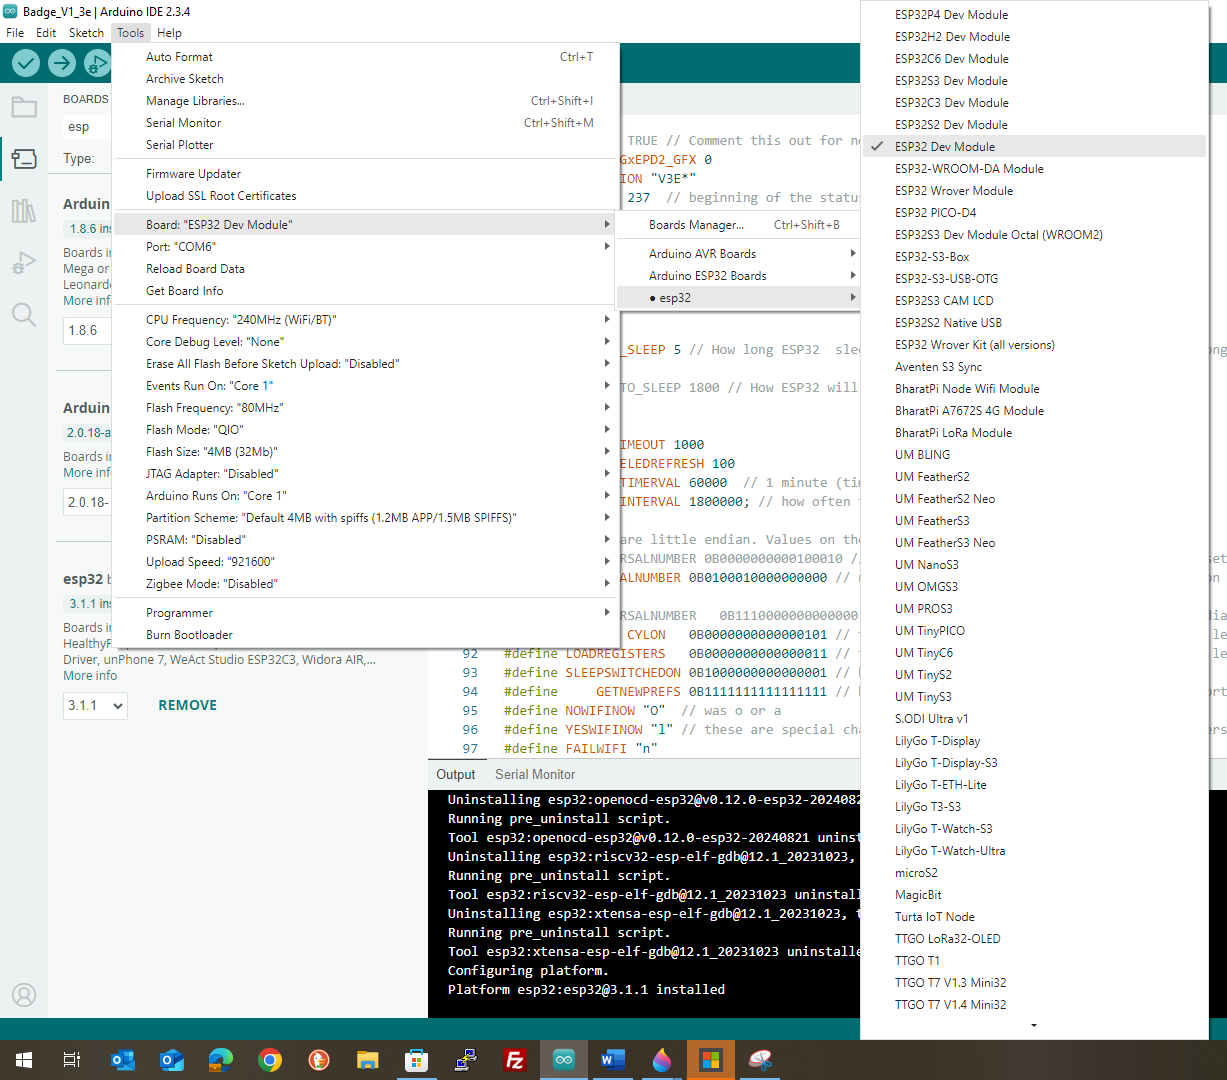
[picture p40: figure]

Figure 6 - board selection test enabled

Board configuration is complete. It should look similar to this when you click on the tools drop down menu without selecting anything. Maybe not exactly as shown, but should have the ESP32 Dev Module showing. That is the important part.

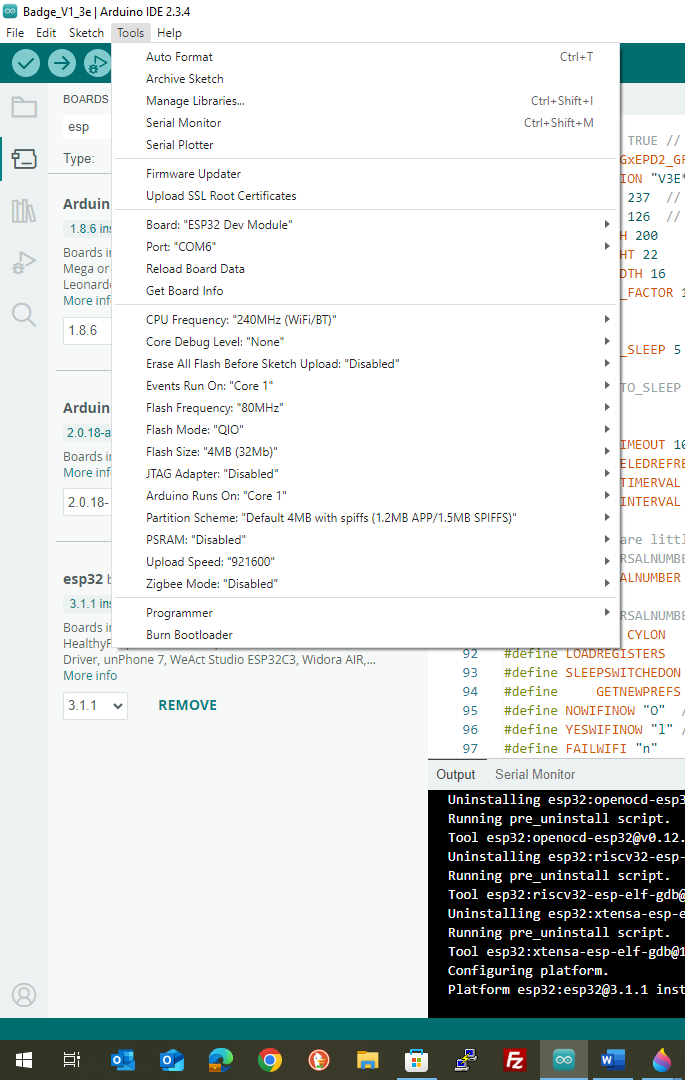
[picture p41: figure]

Figure 7 - Checking to see if the board is instlled.

# Step 2

## Install the libraries

There are two ways to install the libraries. The fest way is to let the Arduino IDE install the library. The other way is to place the library files directly into the library folder. The libraries are in a zip files called libraries.zip on the github site (https://github.com/AntiqueSounds/Tandem-Badge). Unzip and place the folders/files directly into the Documents/Arduino/libraries directory. Once each library is placed, start/restart the Arduino IDE and it should pick up the libraries when it starts. Check this by following the second options and seeing if they reside in the tool.

The second, and best, option is to pull then using the Arduino tool.

Select stair-step menu item:
Sketch/Include libraries/manage libraries... (or CTL-SHIFT-I). This should open a side bar that has a list of libraries.

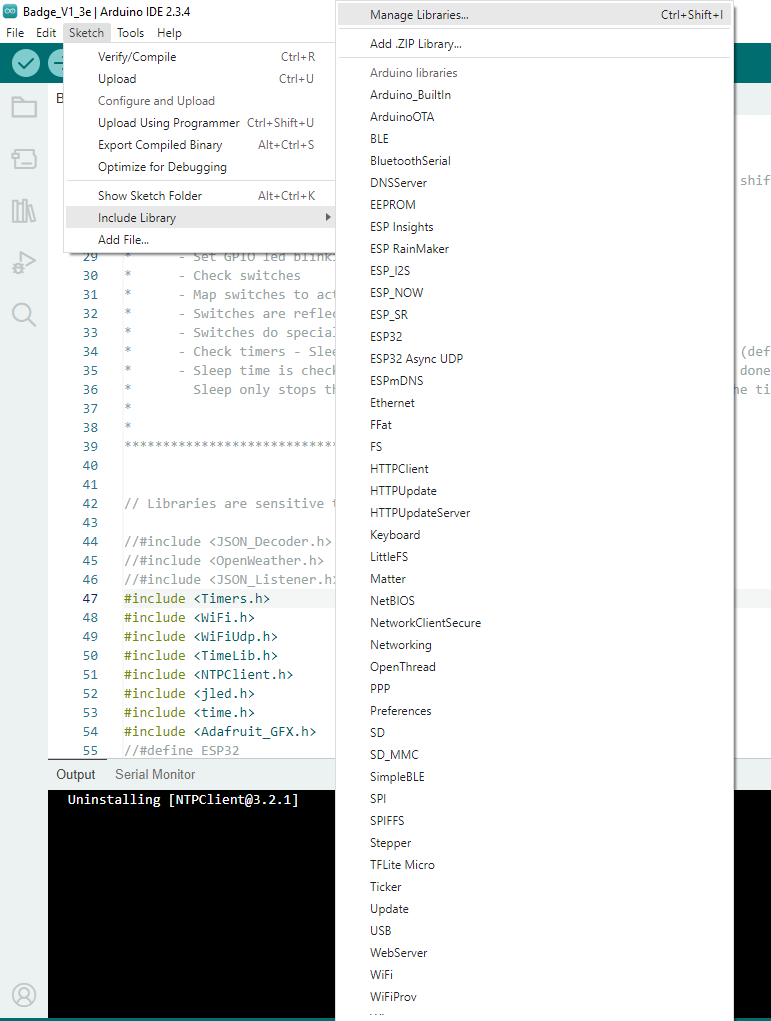
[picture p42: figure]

Figure 8 - Enabling the Library install menu bar

### Install 5 Library Sets

1. NTPCLIENT
2. TIMELIB
3. ADAFRUIT GFX
4. JLED
5. TIMERS

#### NTPCLIENT

The libraries side bar is used to pull and install external libraries. Start by typing “ntpclient” in the search space. You should see several choices. Select the one called NTPClint and select INSTALL button. The version shown might be different than the one in the image below. Let the installation finish.

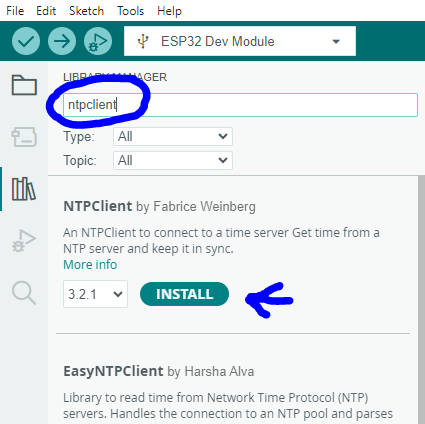
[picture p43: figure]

Figure 9 -Searching for the first library

The install will display in the black status window below.

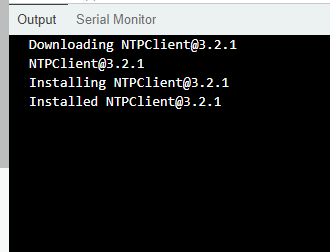
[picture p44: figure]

Figure 10 - log of the installation (for monitoring only)

REPEAT this step for each of the libraries called:

#### TIMELIB

Search “Timelib” (by Michael Margolis)

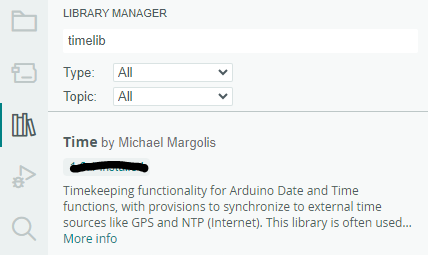
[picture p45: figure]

Figure 11- Timelib - MAKE SURE YOU GET THIS ONE!

#### ADAFRUIT GFX

Seach “Adafruit GFX Library”

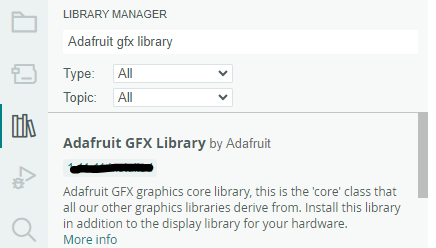
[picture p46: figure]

Figure 12 - Adafruit GFX

#### JLED

Search “JLED” by Jan Delago

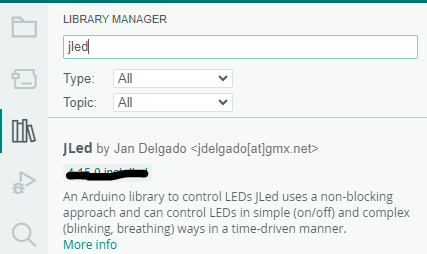
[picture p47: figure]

Figure 13 - JLED LIbrary

#### TIMERS

Search “Timers” by Centaq – Be careful to get this exact one. There are several to choose from. Get this one.

Figure 14 - TIMERS LIBRARY by Centaq

The other libraries should be already available via the ESP board platform libraries. No need to look for those.

# Step 3

## Configure and connect the Display computer via USB

It is a good idea to stop and restart the Arduino IDE after updating everything above.

Please the USB cord into the display device. Use the 90 degree converter on the display side if desired/necessary. Plug the USB into the computer. You may see a device download. Probably not.

Once connected, You need to make sure of two things:

### 1) Make sure that the proper BOARD is selected in the IDE. Stairstep menu selection: Tools/Board/esp/ESP32 Dev Module

It is critical which board type is used. Use ESP32 Dev Module as the board type. If you select the wrong board type, things will appear to work during the compile, but the devices will not function properly, or more likely, strange errors will happen during the compile-and-load step below.

Figure 15 - Selecting the Device

### 2) Select the appropriate Serial communications port and configuration.

Turn the device on now if it is not already on. It only needs to be on for the software to load, but it is a good time to turn it on so that you do not forget later.

Power switch is located at the lower bottom of the underside of the display as part of the electronics of the display board. You will also see the reset buttons. We do not use the rest buttons for any of this.

POWER ON slide switch to the LEFT. POWER OFF slide switch to the right.

In the Arduino IDE software, select Stair-step menu TOOLS/Port/<the COM port >

In the example below, <the COM port> is COM3. Select that – whatever value is presented to you as available for the device. (Sometimes it even shows as Lilygo display.) You can double check this configuration doing just a TOOLS drop-down and looking at the value for Board and for Port. They should both be now set to appropriate values.

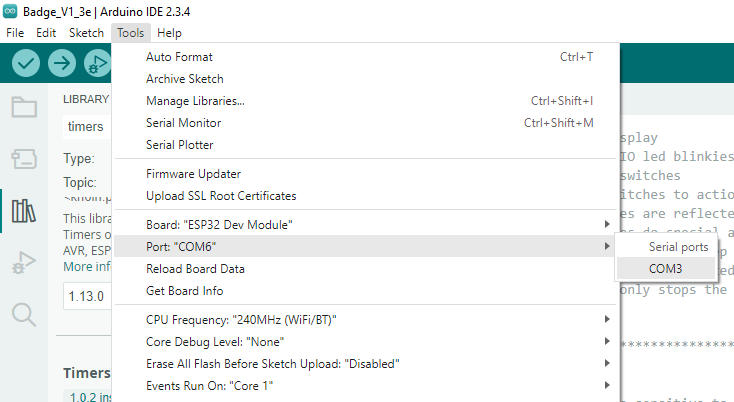
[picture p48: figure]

Figure 16 - Choose the active COM port

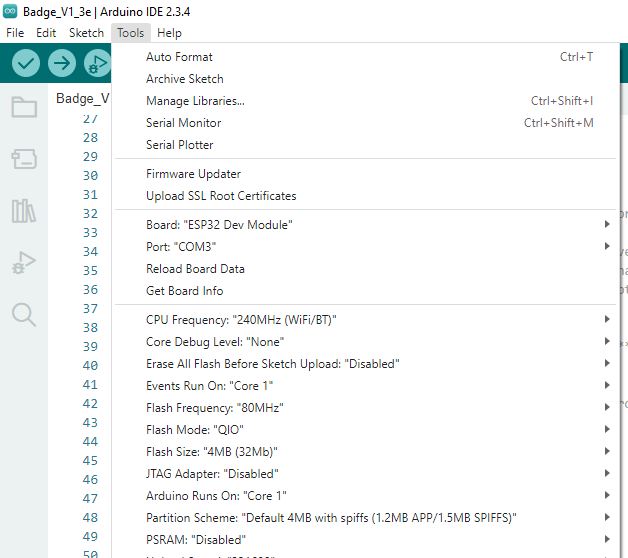
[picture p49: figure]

Figure 17 - Checking the com port and board type (COM VALUE VARIES).

# Step 4

## Compile and load the software

This is the most exciting step. It all comes together now. If anything does not work in this step, go back and re-do/recheck all of the above software installs. Everything you just did is “re-doable” as many times as necessary to get it right.

Best practice is to place the entire folder called Badge_V1_3e into Documents/Arduino (default location of all Arduino source code. aka “sketches”.)

This is made easiest by just pulling the zip file with everything in it. Unzip the file called Badge_V1_3e.zip into Documents\Arduino\. Be sure to place the entire folder with all files underneath.

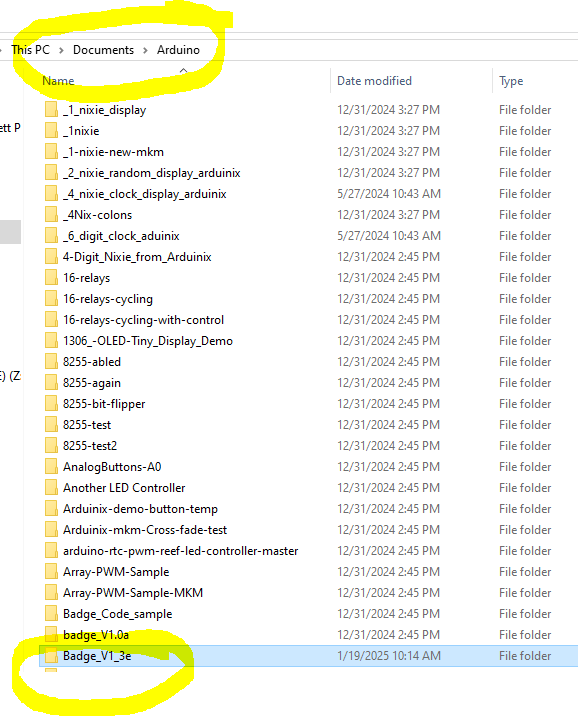
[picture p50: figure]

Figure 18 - Default location of the source sketch files.

It is critical that these three files be inside this folder.

1) Fonts folder – Several files inside. These are obviously the fonts used in the display.
2) Badge source sketch file which is a .ino file. It should be associated to the Arduino IDE as shown.
3) A file call boards.h. This file is imperative in order for the compiler to resolve references to the display type.

All three must reside inside the same directory as the .ino file. The folder itself can reside anywhere, but it is recommended to use the default of Documents\Arduino.

Figure 19 - Contents of the badge sketch folder

#### Compile command and result

The compile/build can be done as a separate step or combined with the upload command. For simplicity we will user the upload command which does both steps.

Use File/Open… to chose the .ino sketch file mentioned above. Use the standard navigation to point to Documents\Arduino\Badge_V1_3e (or wherever you placed it above).


Figure 20 - Standard file open...


Figure 21 - Select source sketch file

Once opened you should see the source.


Figure 22 - Badge source shown - ready to compile and load

Double check that the correct device is showing (highlighted in the above diagram) and check that the COM port is connected and the device is turned on. Ignore any behavior of the device. Display behavior is somewhat random since the device has no software on it yet. It is safe to ignore the display and the led activity.

If everything looks good, and the USB cable is a data cable (not just a power cable), proceed.

Select Sketch/Upload from the menu (or press CTL-U)

The output should start. It will take several seconds to several minutes The first compile will take several MINUTES. Do not fret. The tool caches the builds. But since this is a fresh new build, it must resolve and compile a lot of stuff. Eventually, you will see some significant output.


Figure 23 - Output from compile and load part 1

And eventually…

Figure 24 - Successful compile and load

Once this is completed, the device will reboot and you will see empty/default display. The switches will behave as documented (https://github.com/AntiqueSounds/Tandem-Badge) but the name and Wifi does not work yet. Play as much as you want with the device or can continue. If you are going to continue, leave the device connected to the IDE for the next steps.

# Step 5

## Load personal configuration information into the memory

With the software loaded and the device STILL connected to the Arduino IDE, open the serial terminal inside of the IDE. Select from the menu (CTL-SHIFT-M), Tools/Serial Monitor…


Figure 25 - Select serial monitor from IDE

You should see a few odd messages from the device. Likely they will be garbled.

### Important: Set the serial port communication speed to 115200.

The serial monitor should switch to white at the bottom of the screen and on the far-right side there is a drop down that sets the communication port speed. Set to 115200.


Figure 26 - Set the communication speed

The badge will report lots of errors about Wifi. Ignore these until a message like “Update_Full…” happens. The badge tries hard to connect to Wifi. There is no WiFi configured, hence the noise.

Once the “Update_...” message happen, the device is behaving normally.

### Enable the Configuration prompts from the device

While the badge is running, gently/carefully set ALL of the white lever switches DOWN (“ON” ).

As soon as these switches are set, there should be a prompt on the serial monitor windows.


IMPORTANT: As soon as you see this prompt, TURN ANY ONE OF THE WHITE SWITCHES OFF. Set the switches to anything except “all on”. It is best to do this right away. Otherwise, the prompt will continue until you do reset it. It only does what it is told to do! 😉

The answer is “N” or No. This first time. You want to change these empty values. So responde “N” to the message are. See above diagram circled in red. Place the cursor there and answer “N”

From here on out, there are several prompts. For each, you must respond accurately. If you make a mistake on one, you have to do them ALL over again. You will rarely need to change this, so it should not be a problem. Several values have easy defaults.

Enter first name – Enter any characters and press enter (example here is “Keith” typed into the message are and pressed enter).

Enter last name – Enter any characters

The rest of the prompts I will describe. No need for images.

- Employee number (any value) – Any characters but usually an integer
- Primary Wifi SSID – SSID for connection.
- Primary Wifi Password – password for the primary SSID
- Backup WiFi SSID – A second Wifi option – Place a dummy if not used e.g. NONE
- Backup WiFi Password – Second WiFi Password or none
- TZ (GMT offset in hours) – Enter signed integer for number of hours away from GMT. Eastern US is -5, Central US is -6, etc.
- Zip code 6 digits. This is not currently used. You can default by pressing enter (no value)
- Weather country – Same. Not yet used. Press enter to default to US
- Open weather forecast key – Not used yet. Any value.
- Sleep timer – Integer 0-9999. Number of minutes before the device turns off the LEDs (sleep). Saves battery after this many minutes. Default is 60.
- Do you want to place this into memory? Check the values. Respond accordingly. If No then the prompts start again.

If the devices goes back into prompt mode after you answered “Y/yes”, then you forgot to turn off the switches. Turn them off. You can then simply reset the device (power cycle or press the reset button).

RESTART THE DEVICE! You must restart the device in order for the values to be used in the display. You can turn the device off/on, or press the reset button next to the power slide switch.

# Step 6

## Test it out.

See operating instructions provided on the Github site.


# Final Step

## Enjoy!

I am at nonstoptalker@hpe.com or keithmoore@acm.org.

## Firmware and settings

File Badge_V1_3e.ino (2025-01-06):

/*
Tandem name badge simulation software 
M. Keith Moore
*/
/*****************************************************************************************
* This is the linty version 5 (3e) of the Tandem Badge software. 
* Next version will be delinted and will add a few more features.
* Serial input of the stored configuration values. 
* Stored values are: 
* First Name
* Last Name
* Employee number (any string)
* SSID primary name
* WiFi Password primary
* SSID backup name
* WiFI backup name
* Timezone offset value (hours offset from GMT)  -5 is US eastern
* Zip code for mapping weather location   Not used
* Country code (defaults to US) for future use for weather   Not used 
* Open Weather Key - for future weather update usage  Not used
* Sleep timer - How many minutes with no activity before sleeping. (1-999) Any key toggle re-activates.  
*
*
*
* Functionally, the setup clears the screen and estsblished the pinouts for the shifters and switches.  It draws the baseline display without the time  
* 
* The loop is: 
*      - set display
*      - Set GPIO led blinkies (reset, power, and throbber)
*      - Check switches
*      - Map switches to actions
*      - Switches are reflected above their location in the LED or..
*      - Switches do special actions.  Documented elsewhere.
*      - Check timers - Sleep (below) and minute update times. Every 30 minutes (default) the NTP time will be resynced with the internal clock.  
*      - Sleep time is checked and reset each time a switch is changed. Wake is done by flipping any switch. 
*        Sleep only stops the LEDs.  The WiFi is not active except every time the time is synced to NTP every 30 minutes
*  
*  
*************************************************************************/


// Libraries are sensitive to order.   Take care moving things around. 

//#include <JSON_Decoder.h>
//#include <OpenWeather.h>
//#include <JSON_Listener.h>
#include <Timers.h>
#include <WiFi.h>
#include <WiFiUdp.h>
#include <TimeLib.h>
#include <NTPClient.h>
#include <jled.h>
#include <time.h>
#include <Adafruit_GFX.h>
//#define ESP32

#define LILYGO_T5_V213


//#include "SunMoonCalc.h"
/*
Tandem name badge simulation software 
M. Keith Moore
*/
//#define DEBUG TRUE // Comment this out for non-debug
#define ENABLE_GxEPD2_GFX 0
#define DISVERSION "V3E*"
#define XSTATUS 237  // beginning of the status @ this column
#define YSTATUS 126  // beginning of the status at this row
#define BOXWIDTH 200
#define BOXHEIGHT 22
#define DATA_WIDTH 16
#define uS_TO_S_FACTOR 1000000 // Conversion factor for micro seconds to seconds 

//#ifdef DEBUG
#define TIME_TO_SLEEP 5 // How long ESP32  sleep (in seconds) 5 seconds for testing. - No longer used
//#else
//#define TIME_TO_SLEEP 1800 // How ESP32 will sleep for (in seconds) 30 minutes
//#endif

#define SERIALTIMEOUT 1000
#define BASELINELEDREFRESH 100
#define REFRESHTIMERVAL 60000  // 1 minute (timer in ms) 
#define UPDATE_INTERVAL 1800000; // how often to update time milliseconds  30 mins

// Values here are little endian. Values on the panel are big endian. 
//#define UNIVERSALNUMBER 0B0000000000100010 // normally this should be octal 42. switches set to this turns on the blinkies
#define UNIVERSALNUMBER 0B0100010000000000 // normally this should be octal 42 (big endian on the panel). switches set to this turns on the blinkies

//#define UNIVERSALNUMBER   0B1110000000000000 // this is a test value 7 (the are little endian left side- forced here to right side) 
#define         CYLON   0B0000000000000101 // this is a test value 5 (the are little endian left side- forced here to right side in the code) 
#define LOADREGISTERS   0B0000000000000011 // this is a test value 3 (the are little endian left side- forced here to right side in the code) 
#define SLEEPSWITCHEDON 0B1000000000000001 // high+low value makes me sleepy.
#define     GETNEWPREFS 0B1111111111111111 // high values sets load preferences on serial port  
#define NOWIFINOW "O"  // was o or a
#define YESWIFINOW "l" // these are special characters for the special fonts (meteo and others) 
#define FAILWIFI "n"
#define SLEEPWIFI "2"

#include <Preferences.h>
#include <boards.h>

//#include <GxEPD2_3C.h>
//#include <GxEPD2_4C.h>
//#include <GxEPD2_7C.h>

//#include <GxEPD2_3C.h>
//#include <GxEPD2_4C.h>
//#include <GxEPD2_7C.h>
//#include <GxDEPG0213BN/GxDEPG0213BN.h>    // 2.13" b/w  form DKE GROUP
#include <GxEPD.h>
#include <GxEPD2_BW.h>
#include <GxDEPG0213BN/GxDEPG0213BN.h>    // 2.13" b/w  from DKE GROUP
#define GxEPD2_DRIVER_CLASS GxEPD2_213_BN // DEPG0213BN  122x250, SSD1680, (FPC-7528B), TTGO T5 V2.4.1, V2.3.1
//#define GxEPD2_DRIVER_CLASS GxEPD2_213_GDEY0213B74 // GDEY0213B74 122x250, SSD1680, (FPC-A002 20.04.08)

//#include <SD.h>
//#include <FS.h>

//#include GxEPD_BitmapExamples
// FreeFonts from Adafruit_GFX
// Fonts are located in the libraries/fonts directory under the Adafruit_GFX_Library folder in the fonts folder or in GxEPD2 and in local ./Fonts directory. 

/* These should reside in the GFX library shown here still to confirm the ones that are used and the ones not used. 
* See the fonts.h file to see which ones are active and used
*/

#include <Fonts/data_latin8pt7b.h>
#include <Fonts/data_latin10pt7b.h>
#include <Fonts/data_latin12pt7b.h>
#include <Fonts/data_latin18pt7b.h>
#include <Fonts/data_latin20pt7b.h>
//#include <Fonts/data_latin22pt7b.h>
#include <Fonts/data_latin24pt7b.h>
//#include <Fonts/data_latin28pt7b.h>
#include <Fonts/data_latin30pt7b.h>
//#include <Fonts/data_latin32pt7b.h>
//#include <Fonts/data_latin36pt7b.h>
#include <Fonts/data_latin42pt7b.h>
//#include <Fonts/FreeMonoBold36pt7b.h>
//#include <Fonts/FreeMonoBold42pt7b.h>
//#include <Fonts/FreeMonoBold9pt7b.h>
//#include <Fonts/FreeMonoBold12pt7b.h>
//#include <Fonts/FreeMonoBold18pt7b.h>
//#include <Fonts/FreeMono24pt7b.h>
#include <Fonts/FreeMono18pt7b.h>
//#include <Fonts/FreeSansOblique24pt7b.h>
//#include <Fonts/FreeSansBold24pt7b.h>
#include <Fonts/TomThumb.h>
//#include ./badgefonts/meteocons7pt7b.h
//#include ./badgefonts/meteocons10pt7b.h
#include <Fonts/meteocons12pt7b.h>
//#include ./badgefonts/meteocons14pt7b.h
//#include ./badgefonts/meteocons16pt7b.h
//#include ./badgefonts/WIFI4pt7b.h
//#include ./badgefonts/WIFI6pt7b.h
//#include ./badgefonts/WIFI8pt7b.h
#include <Fonts/WIFI10pt7b.h>
//#include ./badgefonts/WIFI12pt7b.h

// 'wifi_PNG62355', 20x14px
// 'wifi_PNG62355', 20x14px

const unsigned char epd_bitmap_wifi_PNG62355 [] PROGMEM = {
	0x00, 0x00, 0x00, 0x00, 0x00, 0x00, 0x00, 0x00, 0x00, 0x00, 0x00, 0x00, 0x00, 0x00, 0x00, 0x00, 
	0x00, 0x00, 0x00, 0x00, 0x00, 0x00, 0x00, 0x00, 0x00, 0x00, 0x00, 0x00, 0x00, 0x00, 0x00, 0x00, 
	0x00, 0x00, 0x00, 0x00, 0x00, 0x00, 0x00, 0x00, 0x00, 0x00
};

// Array of all bitmaps for convenience. (Total bytes used to store images in PROGMEM = 64)
const int epd_bitmap_allArray_LEN = 1;
const unsigned char* epd_bitmap_allArray[1] = {
	epd_bitmap_wifi_PNG62355
};
//#include <GxIO/GxIO_SPI/GxIO_SPI.h>
#include <GxIO/GxIO.h>
// PL pin 1 
int load =14;   
// CE pin 15       
int clockEnablePin = 4;  
// Q7 pin 7  
int dataIn = 34;   
 // CP pin 2  
int clockIn = 2;   
//flags and toggles
bool alternate = false; // set up for use of two different displays 
bool specialSwitchSet = false; // if special register switches are set for special display features. 
bool noReverse = false;
bool timeToSleep = false; // toggle to put the unit to sleep for TIME_TO_SLEEP amount of time 
bool onlineReady = false;  // used to tell if the WiFi is connected. 
bool timeIsReal = false; // This is returned from the getTime routine and holds that state of the time field validity.
// Define Connections to 74HC595
// ST_CP pin 12
const int latchPin = 27;
// SH_CP pin 11
const int clockPin = 12;
// DS pin 14
const int dataPin = 0; 
 // Define data array
int16_t ledArray[16];
int ledCounter = 0;  // used to hold the current array element 
int ledRefreshDelay = 100; // milliseconds of led time shown
uint16_t ledResult = 0;
uint16_t result, lastResult = 0;  // current switch values
bool flipflop = true;  // used to reversing the LED displays 
int sleepTimeout = 15;
#ifdef DEBUG
int sleepTimerVal = 120000;  // in ms - 2 minute for testing 
#else
int sleepTimerVal= 3600000;  //  1 hour
#endif

//const int vPin = 35;  // was 13 but the board shows pin 35 as battery test? 
const int vPin = 39;  // This is an open pin and can hold voltage-  board shows pin 39 as battery test but no.  
const int throbberPin = 13;  // chevron pin 
const int SAO1Pin = 25;  // SAO pin
const int SAO2Pin = 26;  //  SAO pin
const int resetPin = 32; // Reset LED pin
const int powerPin = 33; // power LED pin
const int LEDGPin = 22; // power LED pin

//GxIO_Class io(SPI,  EPD_CS, EPD_DC,  EPD_RSET);
//GxEPD_Class display(io, EPD_RSET, EPD_BUSY);
GxEPD2_BW<GxEPD2_290_GDEY029T94, GxEPD2_290_GDEY029T94::HEIGHT>
display(GxEPD2_290_GDEY029T94(/*CS=5*/ EPD_CS, /*DC=*/ EPD_DC, /*RST=*/ EPD_RSET, /*BUSY=*/ EPD_BUSY)); // GDEY029T94  128x296, SSD1680, (FPC-A005 20.06.15)

// Setup software PWM for leds. 


auto throbberled = JLed(throbberPin).Breathe(1800).DelayAfter(150).MaxBrightness(20).Forever();
//auto throbberled = JLed(throbberPin).Candle(5 /* speed */, 150 /*jitter*/).Forever();
//auto resetled = JLed(resetPin).Breathe(3000).MinBrightness(10).DelayAfter(500).Repeat(50);
//auto powerled = JLed(powerPin).Breathe(2500).MinBrightness(10).DelayAfter(500).Repeat(50);
//auto resetled = JLed(resetPin).Breathe(2000).MaxBrightness(30).MinBrightness(5).DelayAfter(500).Forever();
//auto powerled = JLed(powerPin).Breathe(3000).MaxBrightness(30).MinBrightness(5).DelayAfter(500).Forever();
auto resetled = JLed(resetPin).Breathe(5000).MaxBrightness(10).Forever();
auto powerled = JLed(powerPin).Breathe(7000).MaxBrightness(10).Forever();
auto SAO1led = JLed(SAO1Pin).Candle(4 /* speed */, 100 /*jitter*/).Forever();
auto SAO2led = JLed(SAO2Pin).Candle(6 /* speed */, 200 /*jitter*/).Forever();
/*
auto throbberled = JLed(jled::Esp32Hal(throbberPin,4)).Breathe(1800).DelayAfter(150).MaxBrightness(20).Forever();
auto resetled = JLed(jled::Esp32Hal(resetPin,3)).Breathe(5000).MaxBrightness(10).Forever();
auto powerled = JLed(jled::Esp32Hal(powerPin,2)).Breathe(7000).MaxBrightness(10).Forever();
auto SAO2led = JLed(jled::Esp32Hal(SAO2Pin,1)).Blink(1000,1000).Forever();
auto SAO1led = JLed(jled::Esp32Hal(SAO1Pin,0)).Blink(1000,1000).Forever();
*/
//auto boardled = JLed(LEDGPin).Breathe(1800).DelayAfter(150).MaxBrightness(20).Forever();
// Setup timer(s)

// We set up just two timers. 
Timers refreshTimer;
Timers sleepTimer;


// set up weather
//OW_Weather ow; // Weather forecast library instance

//const char* ntpServer = "pool.ntp.org";
unsigned long lastUpdate = 0;
unsigned long lastIntervalUpdate = 0;
const long updateInterval = UPDATE_INTERVAL; // how often to update time in seconds
unsigned long lastNTPTime = 0;
const char* ntpServer = "time.nist.gov";
int  gmtOffset_hours = -4;
const long  gmtOffset_sec = gmtOffset_hours * 3600;
const int   daylightOffset_sec = 60000;
// location for weather
float longitude = 44.537;
float latitude = -85.3607;


WiFiUDP udpClient;
NTPClient timeClient(udpClient,ntpServer,gmtOffset_sec,daylightOffset_sec);

// See https://docs.thingpulse.com/how-tos/openweathermap-key/
//String OPEN_WEATHER_MAP_APP_ID = "ec5f1053c471c0d461c4b2ab3e75745e"; // this is my personal used as a defauly
//String OPEN_WEATHER_MAP_LANGUAGE = "en";
//boolean IS_METRIC = true;// PLEASE GET YOUR OWN AND ENTER IT INTO THE PREFS memory using the configuration process. 
/*
Go to https://openweathermap.org/find?q= and search for a location. Go through the
result set and select the entry closest to the actual location you want to display 
data for. It'll be a URL like https://openweathermap.org/city/2657896. The number
at the end is what you assign to the constant below.
 */
//String OPEN_WEATHER_MAP_LOCATION_ID = "49633";
/*
Arabic - ar, Bulgarian - bg, Catalan - ca, Czech - cz, German - de, Greek - el,
English - en, Persian (Farsi) - fa, Finnish - fi, French - fr, Galician - gl,
Croatian - hr, Hungarian - hu, Italian - it, Japanese - ja, Korean - kr,
Latvian - la, Lithuanian - lt, Macedonian - mk, Dutch - nl, Polish - pl,
Portuguese - pt, Romanian - ro, Russian - ru, Swedish - se, Slovak - sk,
Slovenian - sl, Spanish - es, Turkish - tr, Ukrainian - ua, Vietnamese - vi,
Chinese Simplified - zh_cn, Chinese Traditional - zh_tw.
*/


//  THese are obtaned from the persistant memory prefs
String firstName;
String lastName;
String password;
String ssid;
String password2;
String ssid2;
String empNo;
String zipCode = "49633";
String countryCode = "US";
String units = "imperial";

String openWeatherKey = "ec5f1053c471c0d461c4b2ab3e75745e";
int TZ= -5;  // used ony for loadig TZ value. 

// Time and refresh time timers
    unsigned long currentMill = millis(); // grab the time 
    const long displayInterval = 60000; // minute
    unsigned long currentMillSinceLastUpdate = ((currentMill-lastUpdate)%1000);
    unsigned long currentSeconds = lastNTPTime + ((currentMill - lastUpdate)/1000);

// Set up to use flash memory preference library

// Screen display buffers
String input;
String partialScreenBuffer = "      ";
String wifiStatus = FAILWIFI;  // this will be the WIFI font character representing the current Wifi state (a, b, c, etc.) 
// worker values for voltage 
float volts = 0;
float percentage = 0;

Preferences prefs;

//Tandem Computers logo 

// 'Tandem_Chevron-small', 35x34px
//const unsigned char epd_bitmap_Tandem_Chevron_small [] PROGMEM = {
const uint8_t epd_bitmap_Tandem_Chevron [] PROGMEM = {
	0xff, 0xff, 0x07, 0x83, 0xe0, 0xff, 0xfc, 0x07, 0x03, 0xe0, 0xff, 0xf8, 0x1c, 0x07, 0xe0, 0xff, 
	0xf0, 0x38, 0x0e, 0xe0, 0xff, 0xe0, 0x70, 0x1c, 0xe0, 0xff, 0x80, 0xe0, 0x38, 0xe0, 0xff, 0x01, 
	0xc0, 0x70, 0xe0, 0xfe, 0x03, 0x80, 0xf0, 0xe0, 0xfc, 0x07, 0x01, 0xf0, 0xe0, 0xf8, 0x0e, 0x03, 
	0xb0, 0xe0, 0xf0, 0x1c, 0x07, 0x30, 0xe0, 0xe0, 0x38, 0x0e, 0x30, 0xe0, 0x80, 0xf0, 0x1c, 0x30, 
	0xe0, 0xff, 0xff, 0xf8, 0x30, 0xe0, 0xff, 0xff, 0xf0, 0x30, 0xe0, 0xff, 0xff, 0xf0, 0x30, 0xe0, 
	0xff, 0xff, 0xf0, 0x30, 0xe0, 0xff, 0xff, 0xf0, 0x30, 0xe0, 0xff, 0xff, 0xf0, 0x30, 0xe0, 0xff, 
	0xff, 0xf0, 0x31, 0xe0, 0xff, 0xff, 0xf0, 0x33, 0xe0, 0xff, 0xff, 0xf0, 0x33, 0xe0, 0xff, 0xff, 
	0xf0, 0x37, 0xe0, 0xff, 0xff, 0xf0, 0x3f, 0xe0, 0xff, 0xff, 0xf0, 0x3f, 0xe0, 0xff, 0xff, 0xf0, 
	0x3f, 0xe0, 0xff, 0xff, 0xf0, 0x3f, 0xe0, 0xff, 0xff, 0xf0, 0x7f, 0xe0, 0xff, 0xff, 0xf0, 0xff, 
	0xe0, 0xff, 0xff, 0xf1, 0xff, 0xe0, 0xff, 0xff, 0xf3, 0xff, 0xe0, 0xff, 0xff, 0xf3, 0xff, 0xe0, 
	0xff, 0xff, 0xf7, 0xff, 0xe0, 0xff, 0xff, 0xff, 0xff, 0xe0
};
// 'Tandem_Chevron-inverted', 35x34px
const uint8_t epd_bitmap_Tandem_Chevron_inverted [] PROGMEM = {
	0x00, 0x00, 0xf8, 0x7c, 0x00, 0x00, 0x03, 0xf8, 0xfc, 0x00, 0x00, 0x07, 0xe3, 0xf8, 0x00, 0x00, 
	0x0f, 0xc7, 0xf1, 0x00, 0x00, 0x1f, 0x8f, 0xe3, 0x00, 0x00, 0x7f, 0x1f, 0xc7, 0x00, 0x00, 0xfe, 
	0x3f, 0x8f, 0x00, 0x01, 0xfc, 0x7f, 0x0f, 0x00, 0x03, 0xf8, 0xfe, 0x0f, 0x00, 0x07, 0xf1, 0xfc, 
	0x4f, 0x00, 0x0f, 0xe3, 0xf8, 0xcf, 0x00, 0x1f, 0xc7, 0xf1, 0xcf, 0x00, 0x7f, 0x0f, 0xe3, 0xcf, 
	0x00, 0x00, 0x00, 0x07, 0xcf, 0x00, 0x00, 0x00, 0x0f, 0xcf, 0x00, 0x00, 0x00, 0x0f, 0xcf, 0x00, 
	0x00, 0x00, 0x0f, 0xcf, 0x00, 0x00, 0x00, 0x0f, 0xcf, 0x00, 0x00, 0x00, 0x0f, 0xcf, 0x00, 0x00, 
	0x00, 0x0f, 0xce, 0x00, 0x00, 0x00, 0x0f, 0xcc, 0x00, 0x00, 0x00, 0x0f, 0xcc, 0x00, 0x00, 0x00, 
	0x0f, 0xc8, 0x00, 0x00, 0x00, 0x0f, 0xc0, 0x00, 0x00, 0x00, 0x0f, 0xc0, 0x00, 0x00, 0x00, 0x0f, 
	0xc0, 0x00, 0x00, 0x00, 0x0f, 0xc0, 0x00, 0x00, 0x00, 0x0f, 0x80, 0x00, 0x00, 0x00, 0x0f, 0x00, 
	0x00, 0x00, 0x00, 0x0e, 0x00, 0x00, 0x00, 0x00, 0x0c, 0x00, 0x00, 0x00, 0x00, 0x0c, 0x00, 0x00, 
	0x00, 0x00, 0x08, 0x00, 0x00, 0x00, 0x00, 0x00, 0x00, 0x00
};
/* Constructors for the independent LEDs
*  These are: throbber, SAO1, SAO2, Power led, and Reset LED
* These LEDS are managed directly, not through the shift registers using a library for software managed PWM
*/

// SPIClass hspi(HSPI);
/*
bool setupSDCard(void)
{

    return SD.begin(SDCARD_CS);

}
*/
// Worker functions mostly for testing
//Prints all data from weather structure

void printForecast()
{
  // Create the structures that hold the retrieved weather
/* Not done yet
  OW_forecast  *forecast = new OW_forecast;

  Serial.print("\nRequesting weather information from OpenWeather... ");
//ow.getForecast(forecast, OPEN_WEATHER_MAP_APP_ID, latitude, longitude, units, OPEN_WEATHER_MAP_LANGUAGE);
//  ow.getForecast(forecast, api_key, latitude, longitude, units, language);
  Serial.println("Weather from OpenWeather\n");

  Serial.print("city_name           : "); Serial.println(forecast->city_name);
  Serial.print("sunrise             : "); Serial.println(forecast->sunrise);
  Serial.print("sunset              : "); Serial.println(forecast->sunset);
  Serial.print("Latitude            : "); Serial.println(ow.lat);
  Serial.print("Longitude           : "); Serial.println(ow.lon);
  Serial.print("Timezone            : "); Serial.println(forecast->timezone);
  Serial.println();

  if (forecast)
  {
    Serial.println("###############  Forecast weather  ###############\n");
    for (int i = 0; i < (MAX_DAYS * 8); i++)
    {
      Serial.print("3 hourly forecast   "); if (i < 10) Serial.print(" "); Serial.print(i);
      Serial.println();
      Serial.print("dt (time)        : "); Serial.print(forecast->dt[i]);

      Serial.print("temp             : "); Serial.println(forecast->temp[i]);
      Serial.print("temp.min         : "); Serial.println(forecast->temp_min[i]);
      Serial.print("temp.max         : "); Serial.println(forecast->temp_max[i]);

      Serial.print("pressure         : "); Serial.println(forecast->pressure[i]);
      Serial.print("sea_level        : "); Serial.println(forecast->sea_level[i]);
      Serial.print("grnd_level       : "); Serial.println(forecast->grnd_level[i]);
      Serial.print("humidity         : "); Serial.println(forecast->humidity[i]);

      Serial.print("clouds           : "); Serial.println(forecast->clouds_all[i]);
      Serial.print("wind_speed       : "); Serial.println(forecast->wind_speed[i]);
      Serial.print("wind_deg         : "); Serial.println(forecast->wind_deg[i]);
      Serial.print("wind_gust        : "); Serial.println(forecast->wind_gust[i]);

      Serial.print("visibility       : "); Serial.println(forecast->visibility[i]);
      Serial.print("pop              : "); Serial.println(forecast->pop[i]);
      Serial.println();

      Serial.print("dt_txt           : "); Serial.println(forecast->dt_txt[i]);
      Serial.print("id               : "); Serial.println(forecast->id[i]);
      Serial.print("main             : "); Serial.println(forecast->main[i]);
      Serial.print("description      : "); Serial.println(forecast->description[i]);
      Serial.print("icon             : "); Serial.println(forecast->icon[i]);

      Serial.println();
    }
  }
  // Delete to free up space and prevent fragmentation as strings change in length
  delete forecast;
*/
}

/*
//Converts wind direction in degrees to cardinal direction
String windDirection(int direction){
  direction %= 360;
  if(direction >= 349 && direction < 11) return F("N");
  else if(direction < 34) return F("NNE");
  else if(direction < 56) return F("NE");
  else if(direction < 79) return F("ENE");
  else if(direction < 101) return F("E");
  else if(direction < 124) return F("ESE");
  else if(direction < 146) return F("SE");
  else if(direction < 169) return F("SSE");
  else if(direction < 191) return F("S");
  else if(direction < 214) return F("SSW");
  else if(direction < 236) return F("SW");
  else if(direction < 259) return F("WSW");
  else if(direction < 281) return F("W");
  else if(direction < 304) return F("WNW");
  else if(direction < 326) return F("NW");
  return F("NNW");
}

*/

String padWithZeroBelowTen(int d) {
  return d < 10 ? "0" + String(d) : String(d);
}
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
  void loop()
{
    currentMill = millis();
    currentMillSinceLastUpdate = ((currentMill-lastUpdate)%1000);  // time to go get a new time
    currentSeconds = lastNTPTime + ((currentMill - lastUpdate)/1000);
    if (currentMill - lastUpdate >= updateInterval){
      lastUpdate = currentMill;
      timeIsReal = getTime();
      getVoltage();
    }
    else if (currentMill - lastIntervalUpdate >= displayInterval){   // time to refresh display 
        getVoltage();
        lastIntervalUpdate = currentMill; // reset interval 
        if (timeIsReal){
        String minuteStr = String((timeClient.getMinutes() < 10) ? "0" + String(timeClient.getMinutes()) : String(timeClient.getMinutes())); // do not suppress zero
        partialScreenBuffer = String(timeClient.getHours()) + ":" + minuteStr; 
        }
        else partialScreenBuffer = " N/A ";
#ifdef DEBUG 
        Serial.println(partialScreenBuffer); 
#endif 
        showPartialUpdate(partialScreenBuffer);
    };
    updatePWM();
    if (switchCheck(result)){
      processSwitches();
#ifdef DEBUG
    Serial.println("New switch value!");
// Print to serial monitor
  Serial.print("Switch pin states:\r\n");
  print_bytes(result);
#endif
    };
    writeLEDs(); // this procedure will look to see if it is array or standard value
    if (refreshTimer.available()) {
      refreshTimer.stop();
      showPartialUpdate(partialScreenBuffer);
      refreshTimer.start(REFRESHTIMERVAL);// Every minute
  }
  if (sleepTimer.available()) {
      sleepTimer.stop(); 
      sleepTimer.start(sleepTimerVal);// Every sleep timer timout val
        Serial.println("Sleep timer=" + String(sleepTimerVal));
      timeToSleep = true; 
  #ifdef DEBUG
    Serial.println("Sleep timer popped. time to sleep..");
  #endif
  }
  if (timeToSleep){
#ifdef DEBUG
    Serial.println("Going to sleep now.");
#endif
    takeASleepingPill();
#ifdef DEBUG
    Serial.println("Wakey wakey.");
#endif
    wakeUp();
    };
};

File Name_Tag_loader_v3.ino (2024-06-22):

/*
  This is just for loading the permanent storage into the LilyGo ESP. It is not the primary display. 
  See the badge software ("Badge....ino") for the software the uses the persistant values that this tool places into the device. 
*/
#define SERIALTIMEOUT 1000
#include <Preferences.h>
String firstName;
String lastName;
String wifiPassword;
String SSID;
String wifiPassword2;
String SSID2;
String input;
String empNo;
int TZ = -5;
float longitude = 0;
float latitude = 0;

// Set up to use flash memory preference library
Preferences prefs;

void setup(void)
{
    Serial.begin(115200);
    Serial.println();
//    Serial.println("setup");
    Serial.println("*** Tool for entering persistent badge data. This tool is not the full badge.");
    Serial.println("\n Current Values:");
    readMem();
}

int getResponse() {
  // check if data is available
  int rlen = 0;
  Serial.setTimeout(SERIALTIMEOUT);
  while (Serial.available() == 0) {}     //wait for data available
  input = Serial.readString();  //read until timeout
  input.trim();
  return input.length();
  Serial.println(input) ;                       
}

bool getName(){
  int len = 0;
  Serial.setTimeout(SERIALTIMEOUT);
  Serial.flush();
  Serial.print("\nEnter first Name:");
  len = getResponse();
  //strcpy((char *)firstName,input);
  if (len < 1) return false;
  firstName = input;
  firstName.trim(); 
  Serial.println(firstName);  
  
  //delay(1000);
  Serial.print("Enter last name:"); 
  len = getResponse();
  if (len < 1) return false;
  lastName=input;
  lastName.trim();
  Serial.println(lastName);
  Serial.println();
  //delay(1000);

  Serial.print("Employee num (any value):"); 
  len = getResponse();
  if (len < 1) return false;
  //empNo = input.toInt();
  empNo = input;
  if (len > 8)
    empNo.substring(0,8);
  Serial.println(empNo);
 
  Serial.print("Enter Primary SSID:");
  len = getResponse();
  if (len < 1) return false;
  SSID=input;
  SSID.trim();
  Serial.println(SSID);
  delay (1000);

  Serial.print("Enter Primary WiFi Password:");
  len = getResponse();
  if (len < 1) return false;
  wifiPassword=input;
 // wifiPassword=String((char *)input);
  wifiPassword.trim();
  Serial.println(wifiPassword);
  Serial.println();

   Serial.print("Enter backup SSID:");
  len = getResponse();
  if (len < 1) return false;
  SSID2=input;
  SSID2.trim();
  Serial.println(SSID2);
  delay (1000);
  
  Serial.print("Enter backup WiFi Password:");
  len = getResponse();
  if (len < 1) return false;
  wifiPassword2=input;
 // wifiPassword=String((char *)input);
  wifiPassword2.trim();
  Serial.println(wifiPassword2);
  Serial.println();
  
  Serial.print("Enter TZ (GMT offset in hours) Default is -5 Eastern US:");
  len = getResponse();
  if (len < 1) {
    TZ=-5;
  }
  else{
    TZ=input.toInt();
    Serial.println(input);
  }
  Serial.print("Enter weather location longitude (e.g. 44.123)");
  len = getResponse();
  if (len < 1) {
    longitude=43.2633161;
  }
  else{
  longitude=input.toFloat();
  Serial.println(input);
  };  
  Serial.print("Enter weather location latitude (e.g. -2.91)");
  len = getResponse();
  if (len < 1) {
    latitude=-2.9747642;
  }
  else{
  latitude=input.toFloat();
  Serial.println(input);
  };

  if (valid())
    return true;
  else
    return false;
};

bool valid(){
  Serial.println("Current values:");
  Serial.printf("First name=%s\nLast name=%s\nEmployee num=%s\n",firstName,lastName,empNo);
  Serial.printf("SSID=%s\nPassword=%s\n",SSID,wifiPassword);
  Serial.printf("SSID2=%s\nPassword2=%s\n",SSID2,wifiPassword2);
  Serial.printf("Timezone offest=%d\n",TZ);
  Serial.printf("Weather location  Longitude=%e Latitude=%e\n",longitude, latitude);
  Serial.print("Should I place this into memory? (y/n)");
 // Serial.flush();
  getResponse();
  String yn = input;
  yn.trim(); 
  Serial.println("");
  Serial.println(yn);
  input = yn.substring(0,1);
  if (yn == "y" || yn == "Y"){
    return true;
  }
  else{
    Serial.println("Rejected. Try again.");
   return false;  
  };
}; // end validate

bool user_input(){
  Serial.flush();
    Serial.print(">");
  if (Serial.available()){
  getResponse();
  };
  String yn = input;
  yn.trim(); 
  //Serial.println("");
  Serial.println(yn);
  input = yn.substring(0,1);
  if (yn == "y" || yn == "Y"){
    return true;
  }
  else{
//    Serial.println("Rejected. Try again.");
   return false;  
  };
}; // end User_input
void updateMem(){
  if (prefs.begin("name")){
    Serial.print("Updating name...");
    prefs.clear();
    prefs.putString("FirstName",firstName);
    prefs.putString("Lastname",lastName);
//    prefs.putUInt("Empno",empNo);
    prefs.putString("Empno",empNo);
    prefs.end(); // close for name
    Serial.print("Reading name...");
    prefs.getString("FirstName",firstName);
    prefs.getString("Lastname",lastName);
//    prefs.getUInt("Empno",empNo);
    prefs.getString("Empno",empNo);
    Serial.printf("FN=%s LN=%s EMP=%s SSID=%s PW=%s SSID2=%s PW2=%s\n",firstName,lastName,empNo,SSID,wifiPassword,SSID2,wifiPassword2);
  }
  else{
    Serial.println("Error storing the name memory storage.");
  };
  prefs.end(); // close for name

  if (prefs.begin("credentials")){
    Serial.print("Updating credentials...");
    prefs.putString("SSID",SSID);
    prefs.putString("wifiPassword",wifiPassword);
    prefs.putString("SSID2",SSID2);
    prefs.putString("wifiPassword2",String(wifiPassword2));
    prefs.putInt("TZ",TZ);
    prefs.putFloat("longitude",longitude);
    prefs.putFloat("latitude",latitude);
  
    Serial.print("Reading credentials...");
    prefs.getString("SSID",String(SSID));
    prefs.getString("wifiPassword",String(wifiPassword));
    Serial.printf("SSID=%s PW=%s\n",SSID,wifiPassword);
    prefs.getString("SSID2",String(SSID2));
    prefs.getString("wifiPassword2",String(wifiPassword2));
    prefs.getInt("TZ",TZ);
    prefs.getFloat("longitude",longitude);
    prefs.getFloat("latitude",latitude);
  
    Serial.printf("SSID2=%s PW2=%s\n",SSID2,wifiPassword2);
    Serial.printf("TZ=%i Longitude=%e Latitude=%e\n",TZ,longitude,latitude);
  
    prefs.end(); // close for credentials
  }
  else{
    Serial.println("Error storing the credentials memory storage.");
  };
  prefs.end();
};
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

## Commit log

2024-07-26 Update Badge_V1_3d.ino
    Fixed the battery bar logic. v 3.d1
2024-07-29 Update Badge_V1_3d.ino
    Fixed battery display again. Changed logic to show full battery differently than draining one.
2024-08-23 Update Badge_V1_3e.ino
    Fixed the DEBUG output for sleep timer.
    [Badge_V1_3e.ino]
2024-08-23 Update Badge_V1_3e.ino
    Added comments to reflect current functionality.
2024-08-23 Arduino quick start files
2024-10-06 Update README.md
    Changed for the new PCB version 13.
2025-01-06 Update Badge_V1_3e.ino
    Fixed TZ offset
    Fixed secondary SSID
    Removed some lint
    Version is formally named "3e*"
    [Badge_V1_3e.ino]
2025-01-06 Add files via upload
    New boards.h file
2025-01-07 Add files via upload
    Arduino source and fonts and header files
2025-01-20 Added the pre-built folder
    Build instructions leverage a simple folder to drop into Documents\Arduino. This zip file matches the documentation.
2025-02-06 Added Gerber files
